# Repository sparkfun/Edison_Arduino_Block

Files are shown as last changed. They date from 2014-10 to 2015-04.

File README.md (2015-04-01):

SparkFun Edison Arduino Block
=============================

SparkFun Edison Arduino Block

[*SparkFun Edison Arduino Block(DEV-13036)*](https://www.sparkfun.com/products/13036)

Piggyback an Arduino onto your Edison with the Edison Arduino Pro board. This board features the same ATmega328P you'll find on Arduino Uno's, Pro's, and Pro Mini's. The 8-bit microcontroller workhorse is connected to the Edison via a selectable UART, so your Edison can interact with the Arduino over a serial interface.

The GPIO pins of the Arduino are all broken out to the familiar Pro Mini form factor. You can jump wires off of them to control LEDs, motors, or sensors. Or connect it straight up to a Pro Mini shield.

Repository Contents
-------------------
* **/Firmware** - Example Arduino sketch
* **/Hardware** - All Eagle design files (.brd, .sch)
* **/Production** - Test bed files and production panel files

License Information
--------------------
The hardware is released under [Creative Commons ShareAlike 4.0 International](https://creativecommons.org/licenses/by-sa/4.0/).
The code is beerware; if you see me (or any other SparkFun employee) at the local, and you've found our code helpful, please buy us a round!

Distributed as-is; no warranty is given.

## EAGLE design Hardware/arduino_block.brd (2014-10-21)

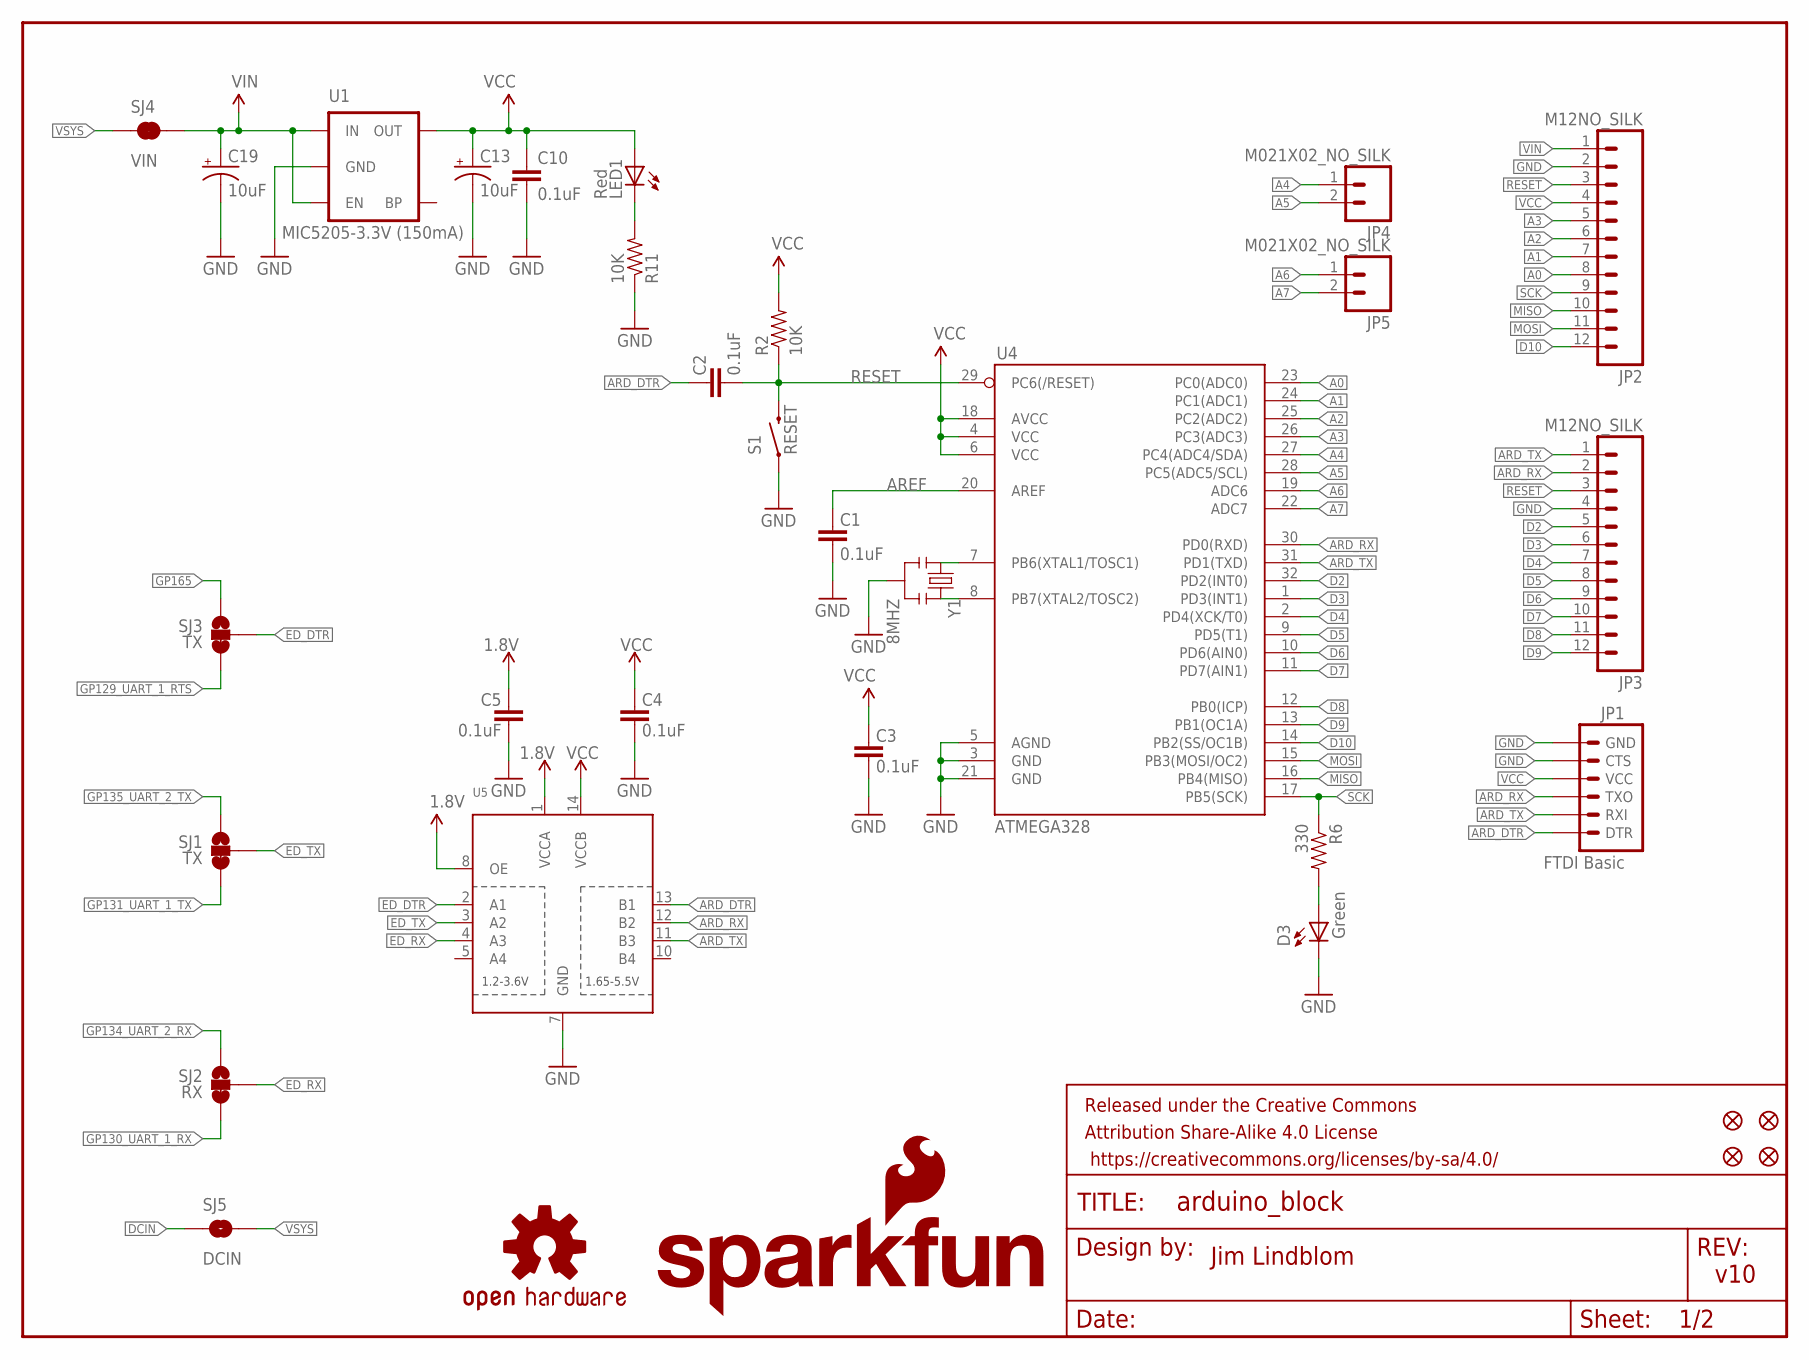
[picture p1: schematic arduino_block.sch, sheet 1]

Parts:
C1, C2, C3, C4, C5, C10: 0.1uF; 0603-CAP
C13, C19: 10uF; EIA3216
D3: Green; 0603-LED-ALT1
FID1, FID2, FID3, FID4: FIDUCIAL1X2; FIDUCIAL-1X2
FRAME1: FRAME-LETTER; CREATIVE_COMMONS
JP1: FTDI Basic; 1X06
JP2, JP3: M12NO_SILK; 1X12_NO_SILK
JP4, JP5: M021X02_NO_SILK; 1X02_NO_SILK
LED1: Red; 0603-LED-ALT1
LOGO1: OSHW-LOGOS; OSHW-LOGO-S
LOGO4: SFE_LOGO_NAME_FLAME.1_INCH; SFE_LOGO_NAME_FLAME_.1
R2, R11: 10K; 0603-RES
R6: 330; 0603-RES
S1: RESET; TACTILE_SWITCH-SMD-RIGHT-ANGLE
SJ1, SJ3: TX; PAD-JUMPER-3-2OF3_NC_BY_TRACE_YES_SILK_FULL_BOX
SJ2: RX; PAD-JUMPER-3-2OF3_NC_BY_TRACE_YES_SILK_FULL_BOX
SJ4: VIN; PAD-JUMPER-2-NC_BY_TRACE_YES_SILK
SJ5: DCIN; PAD-JUMPER-2-NO_YES_SILK
U1: MIC5205-3.3V (150mA); SOT23-5
U4: ATMEGA328; TQFP32-08
U5: TXB0104PWRSOIC14; SO14
Y1: 8MHZ; RESONATOR-SMD

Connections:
1.8V: C5.2, U5.1 (VCCA), U5.8 (OE); also elsewhere on the board
A0: JP2.8, U4.23 (PC0(ADC0))
A1: JP2.7, U4.24 (PC1(ADC1))
A2: JP2.6, U4.25 (PC2(ADC2))
A3: JP2.5, U4.26 (PC3(ADC3))
A4: JP4.1, U4.27 (PC4(ADC4/SDA))
A5: JP4.2, U4.28 (PC5(ADC5/SCL))
A6: JP5.1, U4.19 (ADC6)
A7: JP5.2, U4.22 (ADC7)
ARD_DTR: C2.2, JP1.1 (DTR), U5.13 (B1)
ARD_RX: JP1.3 (TXO), JP3.2, U4.30 (PD0(RXD)), U5.12 (B2)
ARD_TX: JP1.2 (RXI), JP3.1, U4.31 (PD1(TXD)), U5.11 (B3)
AREF: C1.2, U4.20 (AREF)
D2: JP3.5, U4.32 (PD2(INT0))
D3: JP3.6, U4.1 (PD3(INT1))
D4: JP3.7, U4.2 (PD4(XCK/T0))
D5: JP3.8, U4.9 (PD5(T1))
D6: JP3.9, U4.10 (PD6(AIN0))
D7: JP3.10, U4.11 (PD7(AIN1))
D8: JP3.11, U4.12 (PB0(ICP))
D9: JP3.12, U4.13 (PB1(OC1A))
D10: JP2.12, U4.14 (PB2(SS/OC1B))
DCIN: SJ5.1; also elsewhere on the board
ED_DTR: SJ3.2, U5.2 (A1)
ED_RX: SJ2.2, U5.4 (A3)
ED_TX: SJ1.2, U5.3 (A2)
GND: C1.1, C3.1, C4.1, C5.1, C10.2, C13.C (-), C19.C (-), D3.C, JP1.5 (CTS), JP1.6 (GND), JP2.2, JP3.4, R11.1, S1.1, U1.2 (GND), U4.3 (GND), U4.5 (AGND), U4.21 (GND), U5.7 (GND), Y1.2; also elsewhere on the board
GP129_UART_1_RTS: SJ3.3; also elsewhere on the board
GP130_UART_1_RX: SJ2.3; also elsewhere on the board
GP131_UART_1_TX: SJ1.3; also elsewhere on the board
GP134_UART_2_RX: SJ2.1; also elsewhere on the board
GP135_UART_2_TX: SJ1.1; also elsewhere on the board
GP165: SJ3.1; also elsewhere on the board
MISO: JP2.10, U4.16 (PB4(MISO))
MOSI: JP2.11, U4.15 (PB3(MOSI/OC2))
unnamed: U4.8 (PB7(XTAL2/TOSC2)), Y1.3
unnamed: U4.7 (PB6(XTAL1/TOSC1)), Y1.1
unnamed: LED1.C, R11.2
unnamed: D3.A, R6.2
RESET: C2.1, JP2.3, JP3.3, R2.1, S1.2, U4.29 (PC6(/RESET))
SCK: JP2.9, R6.1, U4.17 (PB5(SCK))
VCC: C3.2, C4.2, C10.1, C13.A (+), JP1.4 (VCC), JP2.4, LED1.A, R2.2, U1.5 (OUT), U4.4 (VCC), U4.6 (VCC), U4.18 (AVCC), U5.14 (VCCB)
VIN: C19.A (+), JP2.1, SJ4.2, U1.1 (IN), U1.3 (EN)
VSYS: SJ4.1, SJ5.2; also elsewhere on the board

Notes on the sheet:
v10
Jim Lindblom

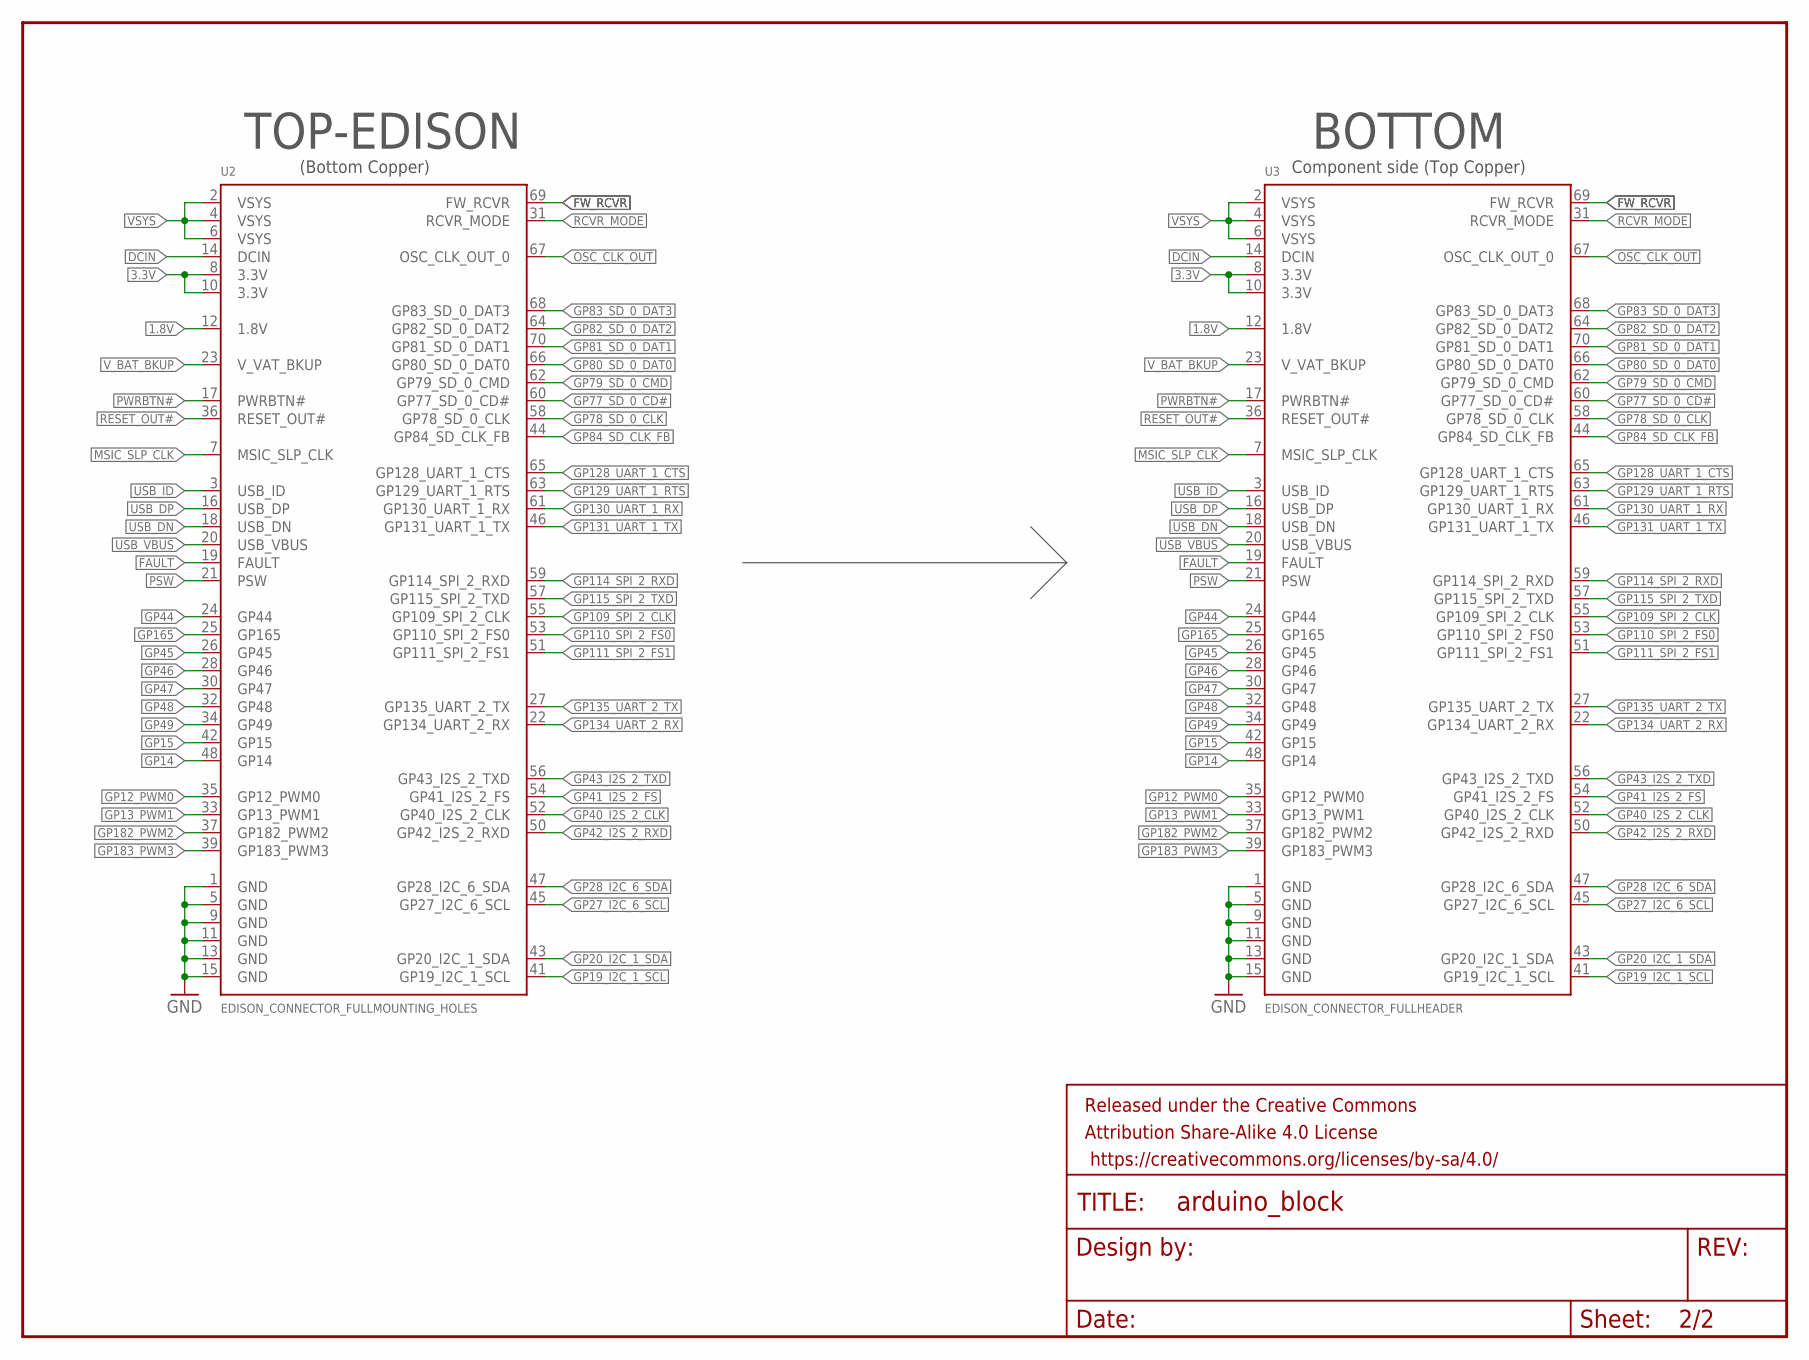
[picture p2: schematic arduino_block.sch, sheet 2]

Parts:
FRAME2: FRAME-LETTER; CREATIVE_COMMONS
U2: EDISON_CONNECTOR_FULLMOUNTING_HOLES; EDISON_DAUGHTER
U3: EDISON_CONNECTOR_FULLHEADER; DF40C-70DP-0.4(51)

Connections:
1.8V: U2.12 (1.8V), U3.12 (1.8V); also elsewhere on the board
3.3V: U2.8 (3.3V), U2.10 (3.3V), U3.8 (3.3V), U3.10 (3.3V)
DCIN: U2.14 (DCIN), U3.14 (DCIN); also elsewhere on the board
FAULT: U2.19 (FAULT), U3.19 (FAULT)
FW_RCVR: U2.69 (FW_RCVR), U3.69 (FW_RCVR)
GND: U2.1 (GND), U2.5 (GND), U2.9 (GND), U2.11 (GND), U2.13 (GND), U2.15 (GND), U3.1 (GND), U3.5 (GND), U3.9 (GND), U3.11 (GND), U3.13 (GND), U3.15 (GND); also elsewhere on the board
GP12_PWM0: U2.35 (GP12_PWM0), U3.35 (GP12_PWM0)
GP13_PWM1: U2.33 (GP13_PWM1), U3.33 (GP13_PWM1)
GP14: U2.48 (GP14), U3.48 (GP14)
GP15: U2.42 (GP15), U3.42 (GP15)
GP19_I2C_1_SCL: U2.41 (GP19_I2C_1_SCL), U3.41 (GP19_I2C_1_SCL)
GP20_I2C_1_SDA: U2.43 (GP20_I2C_1_SDA), U3.43 (GP20_I2C_1_SDA)
GP27_I2C_6_SCL: U2.45 (GP27_I2C_6_SCL), U3.45 (GP27_I2C_6_SCL)
GP28_I2C_6_SDA: U2.47 (GP28_I2C_6_SDA), U3.47 (GP28_I2C_6_SDA)
GP40_I2S_2_CLK: U2.52 (GP40_I2S_2_CLK), U3.52 (GP40_I2S_2_CLK)
GP41_I2S_2_FS: U2.54 (GP41_I2S_2_FS), U3.54 (GP41_I2S_2_FS)
GP42_I2S_2_RXD: U2.50 (GP42_I2S_2_RXD), U3.50 (GP42_I2S_2_RXD)
GP43_I2S_2_TXD: U2.56 (GP43_I2S_2_TXD), U3.56 (GP43_I2S_2_TXD)
GP44: U2.24 (GP44), U3.24 (GP44)
GP45: U2.26 (GP45), U3.26 (GP45)
GP46: U2.28 (GP46), U3.28 (GP46)
GP47: U2.30 (GP47), U3.30 (GP47)
GP48: U2.32 (GP48), U3.32 (GP48)
GP49: U2.34 (GP49), U3.34 (GP49)
GP77_SD_0_CD#: U2.60 (GP77_SD_0_CD#), U3.60 (GP77_SD_0_CD#)
GP78_SD_0_CLK: U2.58 (GP78_SD_0_CLK), U3.58 (GP78_SD_0_CLK)
GP79_SD_0_CMD: U2.62 (GP79_SD_0_CMD), U3.62 (GP79_SD_0_CMD)
GP80_SD_0_DAT0: U2.66 (GP80_SD_0_DAT0), U3.66 (GP80_SD_0_DAT0)
GP81_SD_0_DAT1: U2.70 (GP81_SD_0_DAT1), U3.70 (GP81_SD_0_DAT1)
GP82_SD_0_DAT2: U2.64 (GP82_SD_0_DAT2), U3.64 (GP82_SD_0_DAT2)
GP83_SD_0_DAT3: U2.68 (GP83_SD_0_DAT3), U3.68 (GP83_SD_0_DAT3)
GP84_SD_CLK_FB: U2.44 (GP84_SD_CLK_FB), U3.44 (GP84_SD_CLK_FB)
GP109_SPI_2_CLK: U2.55 (GP109_SPI_2_CLK), U3.55 (GP109_SPI_2_CLK)
GP110_SPI_2_FS0: U2.53 (GP110_SPI_2_FS0), U3.53 (GP110_SPI_2_FS0)
GP111_SPI_2_FS1: U2.51 (GP111_SPI_2_FS1), U3.51 (GP111_SPI_2_FS1)
GP114_SPI_2_RXD: U2.59 (GP114_SPI_2_RXD), U3.59 (GP114_SPI_2_RXD)
GP115_SPI_2_TXD: U2.57 (GP115_SPI_2_TXD), U3.57 (GP115_SPI_2_TXD)
GP128_UART_1_CTS: U2.65 (GP128_UART_1_CTS), U3.65 (GP128_UART_1_CTS)
GP129_UART_1_RTS: U2.63 (GP129_UART_1_RTS), U3.63 (GP129_UART_1_RTS); also elsewhere on the board
GP130_UART_1_RX: U2.61 (GP130_UART_1_RX), U3.61 (GP130_UART_1_RX); also elsewhere on the board
GP131_UART_1_TX: U2.46 (GP131_UART_1_TX), U3.46 (GP131_UART_1_TX); also elsewhere on the board
GP134_UART_2_RX: U2.22 (GP134_UART_2_RX), U3.22 (GP134_UART_2_RX); also elsewhere on the board
GP135_UART_2_TX: U2.27 (GP135_UART_2_TX), U3.27 (GP135_UART_2_TX); also elsewhere on the board
GP165: U2.25 (GP165), U3.25 (GP165); also elsewhere on the board
GP182_PWM2: U2.37 (GP182_PWM2), U3.37 (GP182_PWM2)
GP183_PWM3: U2.39 (GP183_PWM3), U3.39 (GP183_PWM3)
MSIC_SLP_CLK: U2.7 (MSIC_SLP_CLK), U3.7 (MSIC_SLP_CLK)
OSC_CLK_OUT: U2.67 (OSC_CLK_OUT_0), U3.67 (OSC_CLK_OUT_0)
PSW: U2.21 (PSW), U3.21 (PSW)
PWRBTN#: U2.17 (PWRBTN#), U3.17 (PWRBTN#)
RCVR_MODE: U2.31 (RCVR_MODE), U3.31 (RCVR_MODE)
RESET_OUT#: U2.36 (RESET_OUT#), U3.36 (RESET_OUT#)
USB_DN: U2.18 (USB_DN), U3.18 (USB_DN)
USB_DP: U2.16 (USB_DP), U3.16 (USB_DP)
USB_ID: U2.3 (USB_ID), U3.3 (USB_ID)
USB_VBUS: U2.20 (USB_VBUS), U3.20 (USB_VBUS)
VSYS: U2.2 (VSYS), U2.4 (VSYS), U2.6 (VSYS), U3.2 (VSYS), U3.4 (VSYS), U3.6 (VSYS); also elsewhere on the board
V_BAT_BKUP: U2.23 (V_VAT_BKUP), U3.23 (V_VAT_BKUP)

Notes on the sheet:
TOP-EDISON
BOTTOM
Component side (Top Copper)
(Bottom Copper)

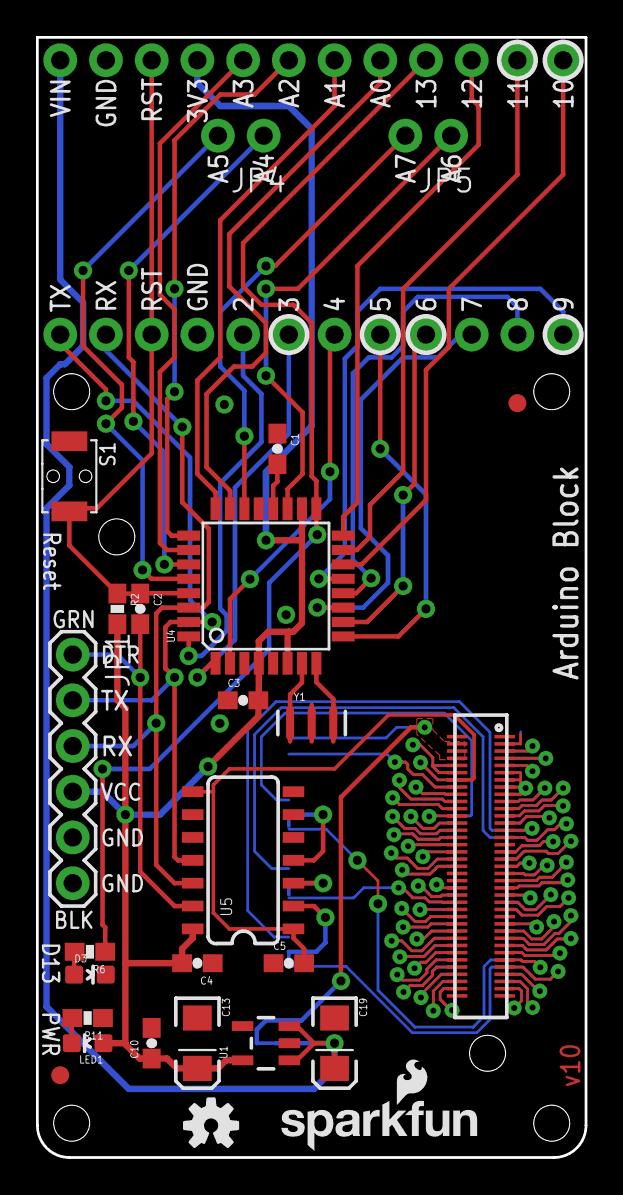
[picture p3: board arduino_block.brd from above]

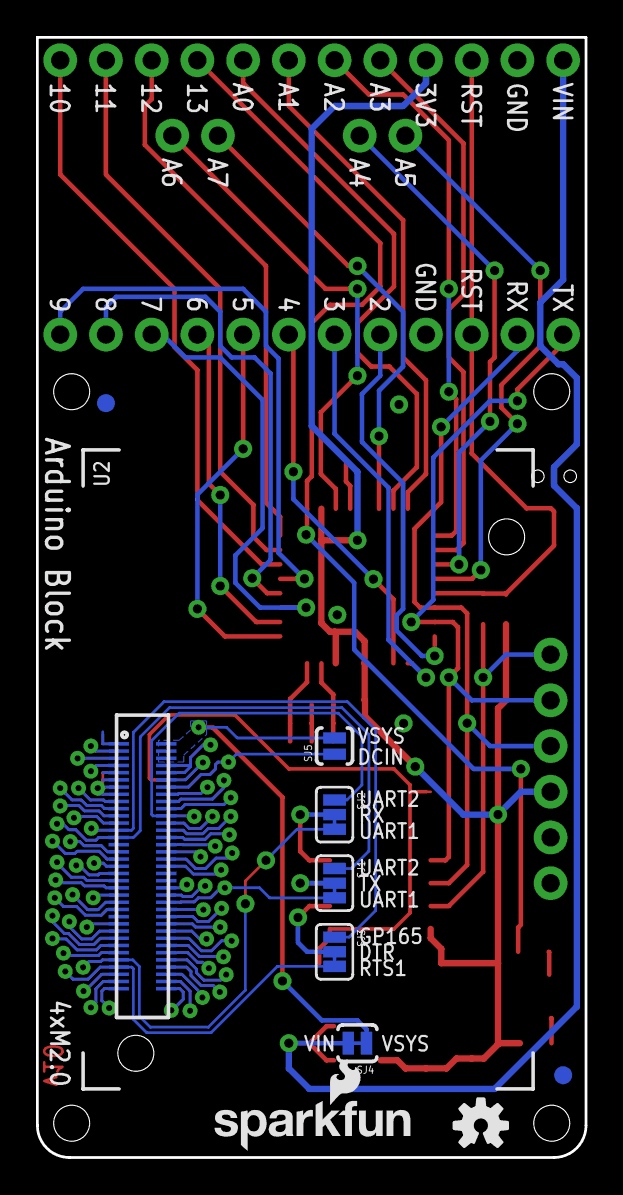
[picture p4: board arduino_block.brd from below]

Board: 2 copper layers, 30.5 x 62.2 mm, 40 parts (11 on the bottom side), 92 nets.

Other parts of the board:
LOGO2: OSHW-LOGOS; OSHW-LOGO-S
LOGO3: SFE_LOGO_NAME_FLAME.1_INCH; SFE_LOGO_NAME_FLAME_.1

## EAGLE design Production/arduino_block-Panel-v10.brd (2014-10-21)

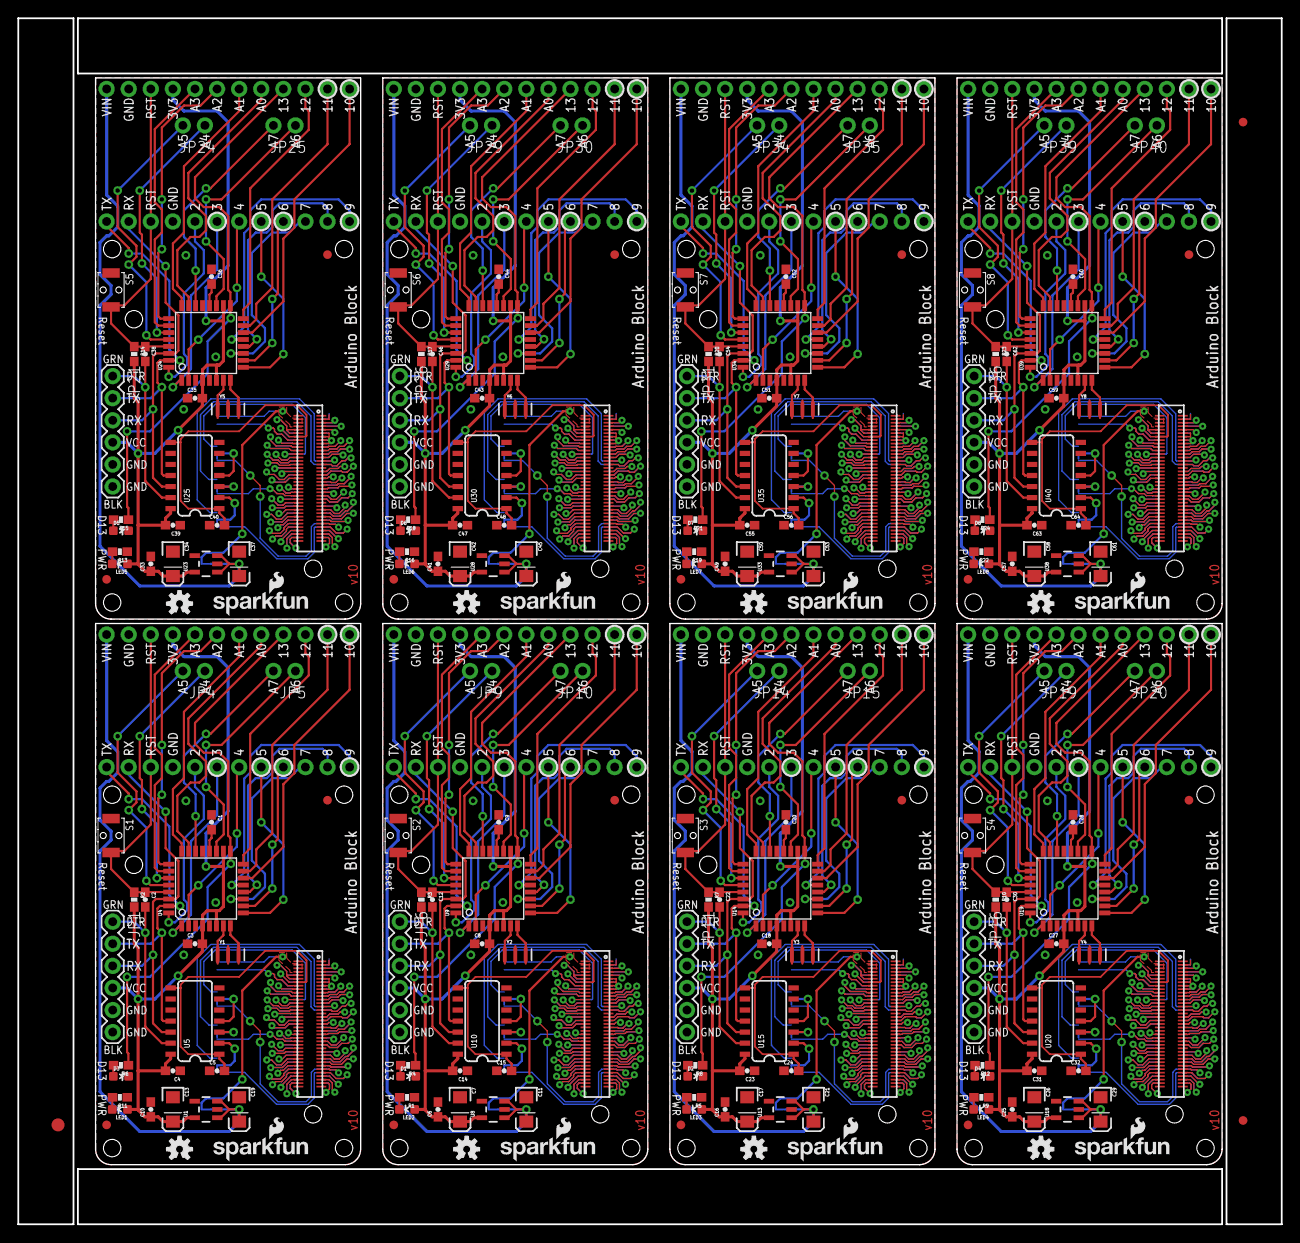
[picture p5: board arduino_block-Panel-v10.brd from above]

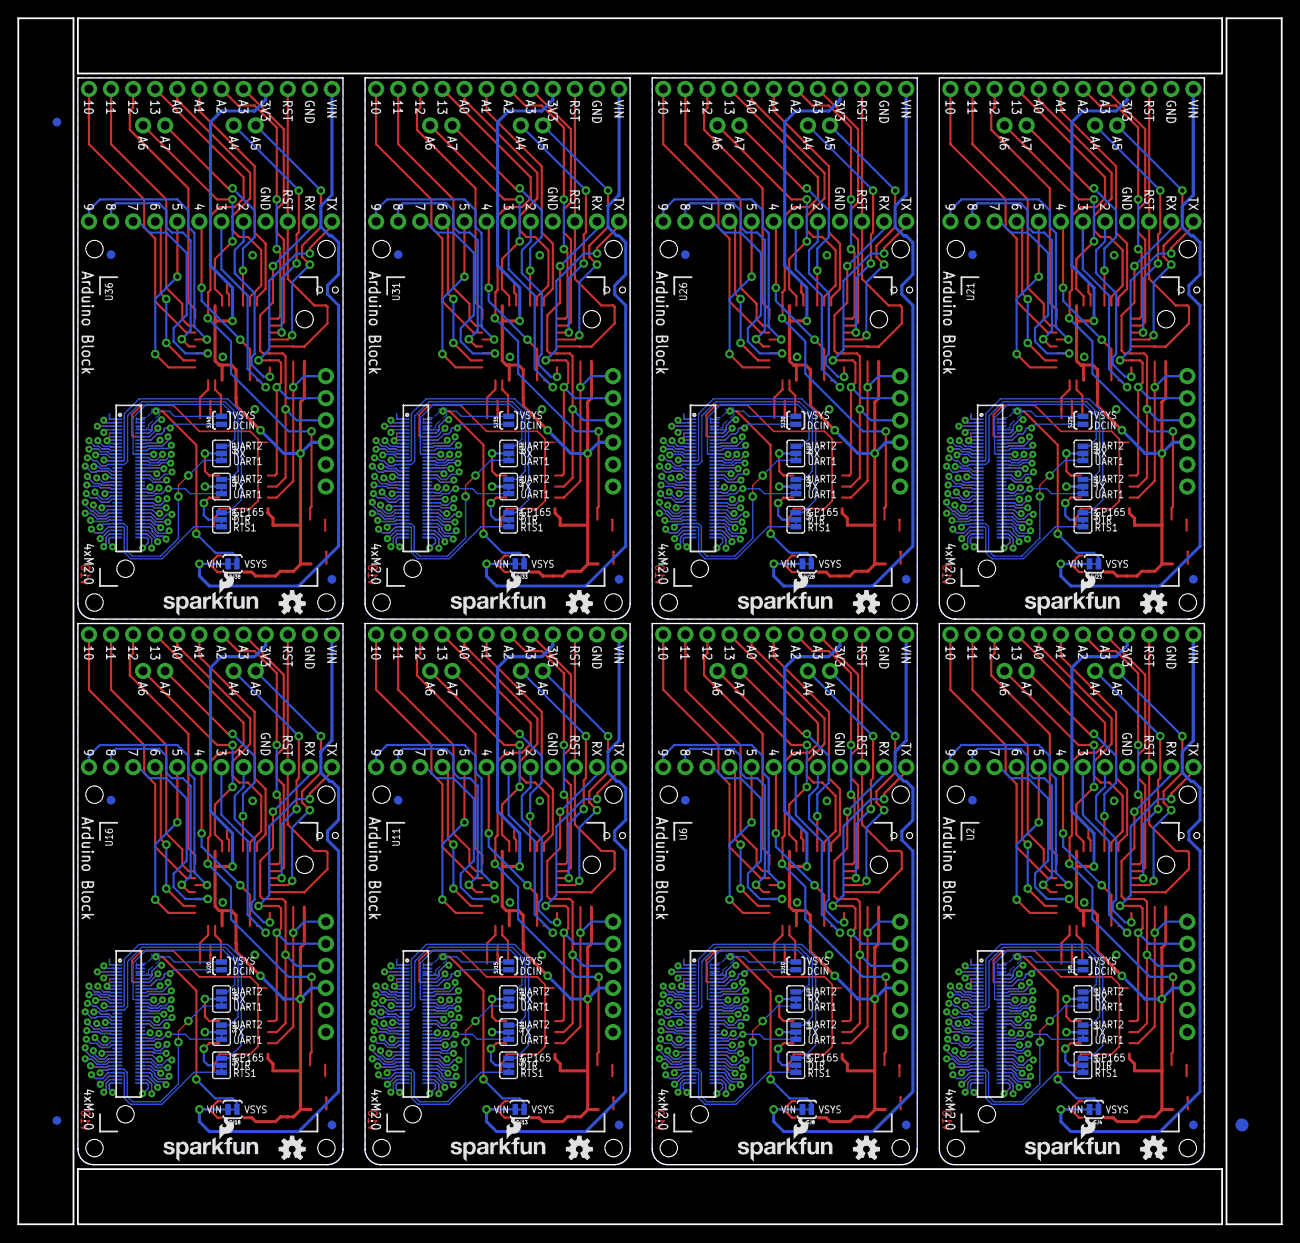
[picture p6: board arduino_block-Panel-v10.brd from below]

Board: 2 copper layers, 145.3 x 138.7 mm, 310 parts (91 on the bottom side), 736 nets.

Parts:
C1, C2, C3, C4, C5, C6, C8, C9, C10, C12, C14, C15, C16, C18, C20, C22, C23, C24, C25, C27, C28, C30, C31, C32, C33, C35, C36, C38, C39, C40, C41, C43, C44, C46, C47, C48, C49, C51, C52, C54, C55, C56, C57, C59, C60, C62, C63, C64: 0.1uF; 0603-CAP
C7, C11, C13, C17, C19, C21, C26, C29, C34, C37, C42, C45, C50, C53, C58, C61: 10uF; EIA3216
D1, D2, D3, D4, D5, D6, D7, D8: Green; 0603-LED-ALT1
E$1, E$2: FIDUCIAL-1.5X3
E$3, E$4, E$5, E$6: FIDUCIAL-1X2
FID1, FID2, FID3, FID4, FID5, FID6, FID7, FID8, FID9, FID10, FID11, FID12, FID13, FID14, FID15, FID16, FID17, FID18, FID19, FID20, FID21, FID22, FID23, FID24, FID25, FID26, FID27, FID28, FID29, FID30, FID31, FID32: FIDUCIAL1X2; FIDUCIAL-1X2
JP1, JP6, JP11, JP16, JP21, JP26, JP31, JP36: FTDI Basic; 1X06
JP2, JP3, JP7, JP8, JP12, JP13, JP17, JP18, JP22, JP23, JP27, JP28, JP32, JP33, JP37, JP38: M12NO_SILK; 1X12_NO_SILK
JP4, JP5, JP9, JP10, JP14, JP15, JP19, JP20, JP24, JP25, JP29, JP30, JP34, JP35, JP39, JP40: M021X02_NO_SILK; 1X02_NO_SILK
LED1, LED2, LED3, LED4, LED5, LED6, LED7, LED8: Red; 0603-LED-ALT1
LOGO1, LOGO2, LOGO5, LOGO7, LOGO9, LOGO11, LOGO13, LOGO15, LOGO17, LOGO19, LOGO21, LOGO23, LOGO25, LOGO27, LOGO29, LOGO31: OSHW-LOGOS; OSHW-LOGO-S
LOGO3, LOGO4, LOGO6, LOGO8, LOGO10, LOGO12, LOGO14, LOGO16, LOGO18, LOGO20, LOGO22, LOGO24, LOGO26, LOGO28, LOGO30, LOGO32: SFE_LOGO_NAME_FLAME.1_INCH; SFE_LOGO_NAME_FLAME_.1
R1, R2, R3, R5, R7, R9, R10, R11, R13, R14, R16, R17, R19, R20, R22, R23: 10K; 0603-RES
R4, R6, R8, R12, R15, R18, R21, R24: 330; 0603-RES
S1, S2, S3, S4, S5, S6, S7, S8: RESET; TACTILE_SWITCH-SMD-RIGHT-ANGLE
SJ1, SJ3, SJ6, SJ9, SJ11, SJ14, SJ16, SJ19, SJ21, SJ24, SJ26, SJ29, SJ31, SJ34, SJ36, SJ39: TX; PAD-JUMPER-3-2OF3_NC_BY_TRACE_YES_SILK_FULL_BOX
SJ2, SJ7, SJ12, SJ17, SJ22, SJ27, SJ32, SJ37: RX; PAD-JUMPER-3-2OF3_NC_BY_TRACE_YES_SILK_FULL_BOX
SJ4, SJ8, SJ13, SJ18, SJ23, SJ28, SJ33, SJ38: VIN; PAD-JUMPER-2-NC_BY_TRACE_YES_SILK
SJ5, SJ10, SJ15, SJ20, SJ25, SJ30, SJ35, SJ40: DCIN; PAD-JUMPER-2-NO_YES_SILK
U1, U8, U13, U18, U23, U28, U33, U38: MIC5205-3.3V (150mA); SOT23-5
U2, U6, U11, U16, U21, U26, U31, U36: EDISON_CONNECTOR_FULLMOUNTING_HOLES; EDISON_DAUGHTER
U3, U7, U12, U17, U22, U27, U32, U37: EDISON_CONNECTOR_FULLHEADER; DF40C-70DP-0.4(51)
U4, U9, U14, U19, U24, U29, U34, U39: ATMEGA328; TQFP32-08
U5, U10, U15, U20, U25, U30, U35, U40: SO14
Y1, Y2, Y3, Y4, Y5, Y6, Y7, Y8: 8MHZ; RESONATOR-SMD

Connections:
1.8V: C5.2, U2.12, U3.12, U5.1, U5.8
1.8V1: C15.2, U6.12, U7.12, U10.1, U10.8
1.8V2: C24.2, U11.12, U12.12, U15.1, U15.8
1.8V3: C32.2, U16.12, U17.12, U20.1, U20.8
1.8V4: C40.2, U21.12, U22.12, U25.1, U25.8
1.8V5: C48.2, U26.12, U27.12, U30.1, U30.8
1.8V6: C56.2, U31.12, U32.12, U35.1, U35.8
1.8V7: C64.2, U36.12, U37.12, U40.1, U40.8
3.3V: U2.8, U2.10, U3.8, U3.10
3.3V1: U6.8, U6.10, U7.8, U7.10
3.3V2: U11.8, U11.10, U12.8, U12.10
3.3V3: U16.8, U16.10, U17.8, U17.10
3.3V4: U21.8, U21.10, U22.8, U22.10
3.3V5: U26.8, U26.10, U27.8, U27.10
3.3V6: U31.8, U31.10, U32.8, U32.10
3.3V7: U36.8, U36.10, U37.8, U37.10
A0: JP2.8, U4.23
A1: JP2.7, U4.24
A2: JP2.6, U4.25
A3: JP2.5, U4.26
A4: JP4.1, U4.27
A5: JP4.2, U4.28
A6: JP5.1, U4.19
A7: JP5.2, U4.22
A8: JP9.2, U9.28
A9: JP9.1, U9.27
A10: JP7.5, U9.26
A11: JP7.6, U9.25
A12: JP7.7, U9.24
A13: JP7.8, U9.23
A14: JP10.1, U9.19
A15: JP10.2, U9.22
A16: JP14.2, U14.28
A17: JP14.1, U14.27
A18: JP12.5, U14.26
A19: JP12.6, U14.25
A20: JP12.7, U14.24
A21: JP12.8, U14.23
A22: JP15.1, U14.19
A23: JP15.2, U14.22
A24: JP19.2, U19.28
A25: JP19.1, U19.27
A26: JP17.5, U19.26
A27: JP17.6, U19.25
A28: JP17.7, U19.24
A29: JP17.8, U19.23
A30: JP20.1, U19.19
A31: JP20.2, U19.22
A32: JP24.2, U24.28
A33: JP24.1, U24.27
A34: JP22.5, U24.26
A35: JP22.6, U24.25
A36: JP22.7, U24.24
A37: JP22.8, U24.23
A38: JP25.1, U24.19
A39: JP25.2, U24.22
A40: JP29.2, U29.28
A41: JP29.1, U29.27
A42: JP27.5, U29.26
A43: JP27.6, U29.25
A44: JP27.7, U29.24
A45: JP27.8, U29.23
A46: JP30.1, U29.19
A47: JP30.2, U29.22
A48: JP34.2, U34.28
A49: JP34.1, U34.27
A50: JP32.5, U34.26
A51: JP32.6, U34.25
A52: JP32.7, U34.24
A53: JP32.8, U34.23
A54: JP35.1, U34.19
A55: JP35.2, U34.22
A56: JP39.2, U39.28
A57: JP39.1, U39.27
A58: JP37.5, U39.26
A59: JP37.6, U39.25
A60: JP37.7, U39.24
A61: JP37.8, U39.23
A62: JP40.1, U39.19
A63: JP40.2, U39.22
ARD_DTR: C2.2, JP1.1, U5.13
ARD_DTR1: C12.2, JP6.1, U10.13
ARD_DTR2: C22.2, JP11.1, U15.13
ARD_DTR3: C30.2, JP16.1, U20.13
ARD_DTR4: C38.2, JP21.1, U25.13
ARD_DTR5: C46.2, JP26.1, U30.13
ARD_DTR6: C54.2, JP31.1, U35.13
ARD_DTR7: C62.2, JP36.1, U40.13
ARD_RX: JP1.3, JP3.2, U4.30, U5.12
ARD_RX1: JP6.3, JP8.2, U9.30, U10.12
ARD_RX2: JP11.3, JP13.2, U14.30, U15.12
ARD_RX3: JP16.3, JP18.2, U19.30, U20.12
ARD_RX4: JP21.3, JP23.2, U24.30, U25.12
ARD_RX5: JP26.3, JP28.2, U29.30, U30.12
ARD_RX6: JP31.3, JP33.2, U34.30, U35.12
ARD_RX7: JP36.3, JP38.2, U39.30, U40.12
ARD_TX: JP1.2, JP3.1, U4.31, U5.11
ARD_TX1: JP6.2, JP8.1, U9.31, U10.11
ARD_TX2: JP11.2, JP13.1, U14.31, U15.11
ARD_TX3: JP16.2, JP18.1, U19.31, U20.11
ARD_TX4: JP21.2, JP23.1, U24.31, U25.11
ARD_TX5: JP26.2, JP28.1, U29.31, U30.11
ARD_TX6: JP31.2, JP33.1, U34.31, U35.11
ARD_TX7: JP36.2, JP38.1, U39.31, U40.11
AREF: C1.2, U4.20
AREF1: C9.2, U9.20
AREF2: C20.2, U14.20
AREF3: C28.2, U19.20
AREF4: C36.2, U24.20
AREF5: C44.2, U29.20
AREF6: C52.2, U34.20
AREF7: C60.2, U39.20
D1: JP8.12, U9.13
D2: JP3.5, U4.32
D3: JP3.6, U4.1
D4: JP3.7, U4.2
D5: JP3.8, U4.9
D6: JP3.9, U4.10
D7: JP3.10, U4.11
D8: JP3.11, U4.12
D9: JP3.12, U4.13
D10: JP2.12, U4.14
D11: JP8.11, U9.12
D12: JP8.5, U9.32
D13: JP8.6, U9.1
D14: JP8.7, U9.2
D15: JP8.8, U9.9
D16: JP8.9, U9.10
D17: JP8.10, U9.11
D18: JP7.12, U9.14
D19: JP13.12, U14.13
D20: JP13.11, U14.12
D21: JP13.5, U14.32
D22: JP13.6, U14.1
D23: JP13.7, U14.2
D24: JP13.8, U14.9
D25: JP13.9, U14.10
D26: JP13.10, U14.11
D27: JP12.12, U14.14
D28: JP18.12, U19.13
D29: JP18.11, U19.12
D30: JP18.5, U19.32
D31: JP18.6, U19.1
D32: JP18.7, U19.2
D33: JP18.8, U19.9
D34: JP18.9, U19.10
D35: JP18.10, U19.11
D36: JP17.12, U19.14
D37: JP23.12, U24.13
D38: JP23.11, U24.12
D39: JP23.5, U24.32
D40: JP23.6, U24.1
D41: JP23.7, U24.2
D42: JP23.8, U24.9
D43: JP23.9, U24.10
D44: JP23.10, U24.11
D45: JP22.12, U24.14
D46: JP28.12, U29.13
D47: JP28.11, U29.12
D48: JP28.5, U29.32
D49: JP28.6, U29.1
D50: JP28.7, U29.2
D51: JP28.8, U29.9
D52: JP28.9, U29.10
D53: JP28.10, U29.11
D54: JP27.12, U29.14
D55: JP33.12, U34.13
D56: JP33.11, U34.12
D57: JP33.5, U34.32
D58: JP33.6, U34.1
D59: JP33.7, U34.2
D60: JP33.8, U34.9
D61: JP33.9, U34.10
D62: JP33.10, U34.11
D63: JP32.12, U34.14
D64: JP38.12, U39.13
D65: JP38.11, U39.12
D66: JP38.5, U39.32
D67: JP38.6, U39.1
D68: JP38.7, U39.2
D69: JP38.8, U39.9
D70: JP38.9, U39.10
D71: JP38.10, U39.11
D72: JP37.12, U39.14
DCIN: SJ5.1, U2.14, U3.14
DCIN1: SJ10.1, U6.14, U7.14
DCIN2: SJ15.1, U11.14, U12.14
DCIN3: SJ20.1, U16.14, U17.14
DCIN4: SJ25.1, U21.14, U22.14
DCIN5: SJ30.1, U26.14, U27.14
DCIN6: SJ35.1, U31.14, U32.14
DCIN7: SJ40.1, U36.14, U37.14
ED_DTR: SJ3.2, U5.2
ED_DTR1: SJ9.2, U10.2
ED_DTR2: SJ14.2, U15.2
ED_DTR3: SJ19.2, U20.2
ED_DTR4: SJ24.2, U25.2
ED_DTR5: SJ29.2, U30.2
ED_DTR6: SJ34.2, U35.2
ED_DTR7: SJ39.2, U40.2
ED_RX: SJ2.2, U5.4
ED_RX1: SJ7.2, U10.4
ED_RX2: SJ12.2, U15.4
ED_RX3: SJ17.2, U20.4
ED_RX4: SJ22.2, U25.4
ED_RX5: SJ27.2, U30.4
ED_RX6: SJ32.2, U35.4
ED_RX7: SJ37.2, U40.4
ED_TX: SJ1.2, U5.3
ED_TX1: SJ6.2, U10.3
ED_TX2: SJ11.2, U15.3
ED_TX3: SJ16.2, U20.3
ED_TX4: SJ21.2, U25.3
ED_TX5: SJ26.2, U30.3
ED_TX6: SJ31.2, U35.3
ED_TX7: SJ36.2, U40.3
FAULT: U2.19, U3.19
FAULT1: U6.19, U7.19
FAULT2: U11.19, U12.19
FAULT3: U16.19, U17.19
FAULT4: U21.19, U22.19
FAULT5: U26.19, U27.19
FAULT6: U31.19, U32.19
FAULT7: U36.19, U37.19
FW_RCVR: U2.69, U3.69
FW_RCVR1: U6.69, U7.69
FW_RCVR2: U11.69, U12.69
FW_RCVR3: U16.69, U17.69
FW_RCVR4: U21.69, U22.69
FW_RCVR5: U26.69, U27.69
FW_RCVR6: U31.69, U32.69
FW_RCVR7: U36.69, U37.69
GND: C1.1, C3.1, C4.1, C5.1, C10.2, C13.C, C19.C, D3.C, JP1.5, JP1.6, JP2.2, JP3.4, R11.1, S1.1, U1.2, U2.1, U2.5, U2.9, U2.11, U2.13, U2.15, U3.1, U3.5, U3.9, U3.11, U3.13, U3.15, U4.3, U4.5, U4.21, U5.7, Y1.2
GND1: C6.2, C7.C, C8.1, C9.1, C11.C, C14.1, C15.1, D1.C, JP6.5, JP6.6, JP7.2, JP8.4, R1.1, S2.1, U6.1, U6.5, U6.9, U6.11, U6.13, U6.15, U7.1, U7.5, U7.9, U7.11, U7.13, U7.15, U8.2, U9.3, U9.5, U9.21, U10.7, Y2.2
GND2: C16.2, C17.C, C18.1, C20.1, C21.C, C23.1, C24.1, D2.C, JP11.5, JP11.6, JP12.2, JP13.4, R5.1, S3.1, U11.1, U11.5, U11.9, U11.11, U11.13, U11.15, U12.1, U12.5, U12.9, U12.11, U12.13, U12.15, U13.2, U14.3, U14.5, U14.21, U15.7, Y3.2
GND3: C25.2, C26.C, C27.1, C28.1, C29.C, C31.1, C32.1, D4.C, JP16.5, JP16.6, JP17.2, JP18.4, R9.1, S4.1, U16.1, U16.5, U16.9, U16.11, U16.13, U16.15, U17.1, U17.5, U17.9, U17.11, U17.13, U17.15, U18.2, U19.3, U19.5, U19.21, U20.7, Y4.2
GND4: C33.2, C34.C, C35.1, C36.1, C37.C, C39.1, C40.1, D5.C, JP21.5, JP21.6, JP22.2, JP23.4, R13.1, S5.1, U21.1, U21.5, U21.9, U21.11, U21.13, U21.15, U22.1, U22.5, U22.9, U22.11, U22.13, U22.15, U23.2, U24.3, U24.5, U24.21, U25.7, Y5.2
GND5: C41.2, C42.C, C43.1, C44.1, C45.C, C47.1, C48.1, D6.C, JP26.5, JP26.6, JP27.2, JP28.4, R16.1, S6.1, U26.1, U26.5, U26.9, U26.11, U26.13, U26.15, U27.1, U27.5, U27.9, U27.11, U27.13, U27.15, U28.2, U29.3, U29.5, U29.21, U30.7, Y6.2
GND6: C49.2, C50.C, C51.1, C52.1, C53.C, C55.1, C56.1, D7.C, JP31.5, JP31.6, JP32.2, JP33.4, R19.1, S7.1, U31.1, U31.5, U31.9, U31.11, U31.13, U31.15, U32.1, U32.5, U32.9, U32.11, U32.13, U32.15, U33.2, U34.3, U34.5, U34.21, U35.7, Y7.2
GND7: C57.2, C58.C, C59.1, C60.1, C61.C, C63.1, C64.1, D8.C, JP36.5, JP36.6, JP37.2, JP38.4, R22.1, S8.1, U36.1, U36.5, U36.9, U36.11, U36.13, U36.15, U37.1, U37.5, U37.9, U37.11, U37.13, U37.15, U38.2, U39.3, U39.5, U39.21, U40.7, Y8.2
GP1: U6.48, U7.48
GP2: U6.42, U7.42
GP3: U6.34, U7.34
GP4: U6.32, U7.32
GP5: U6.30, U7.30
GP6: U6.28, U7.28
GP7: U6.26, U7.26
GP8: SJ9.1, U6.25, U7.25
GP9: U6.24, U7.24
GP10: U11.48, U12.48
GP11: U11.42, U12.42
GP12: U11.34, U12.34
GP12_PWM0: U2.35, U3.35
GP12_PWM1: U6.35, U7.35
GP12_PWM2: U11.35, U12.35
GP12_PWM3: U16.35, U17.35
GP12_PWM4: U21.35, U22.35
GP12_PWM5: U26.35, U27.35
GP12_PWM6: U31.35, U32.35
GP12_PWM7: U36.35, U37.35
GP13: U11.32, U12.32
GP13_PWM1: U2.33, U3.33
GP13_PWM2: U6.33, U7.33
GP13_PWM3: U11.33, U12.33
GP13_PWM4: U16.33, U17.33
GP13_PWM5: U21.33, U22.33
GP13_PWM6: U26.33, U27.33
GP13_PWM7: U31.33, U32.33
GP13_PWM8: U36.33, U37.33
GP14: U2.48, U3.48
GP15: U2.42, U3.42
GP16: U11.30, U12.30
GP17: U11.28, U12.28
GP18: U11.26, U12.26
GP19: SJ14.1, U11.25, U12.25
GP19_I2C_1_SCL: U2.41, U3.41
GP19_I2C_1_SCL1: U6.41, U7.41
GP19_I2C_1_SCL2: U11.41, U12.41
GP19_I2C_1_SCL3: U16.41, U17.41
GP19_I2C_1_SCL4: U21.41, U22.41
GP19_I2C_1_SCL5: U26.41, U27.41
GP19_I2C_1_SCL6: U31.41, U32.41
GP19_I2C_1_SCL7: U36.41, U37.41
GP20: U11.24, U12.24
GP20_I2C_1_SDA: U2.43, U3.43
GP20_I2C_1_SDA1: U6.43, U7.43
GP20_I2C_1_SDA2: U11.43, U12.43
GP20_I2C_1_SDA3: U16.43, U17.43
GP20_I2C_1_SDA4: U21.43, U22.43
GP20_I2C_1_SDA5: U26.43, U27.43
GP20_I2C_1_SDA6: U31.43, U32.43
GP20_I2C_1_SDA7: U36.43, U37.43
GP21: U16.48, U17.48
GP22: U16.42, U17.42
GP23: U16.34, U17.34
GP24: U16.32, U17.32
GP25: U16.30, U17.30
GP26: U16.28, U17.28
GP27: U16.26, U17.26
GP27_I2C_6_SCL: U2.45, U3.45
GP27_I2C_6_SCL1: U6.45, U7.45
GP27_I2C_6_SCL2: U11.45, U12.45
GP27_I2C_6_SCL3: U16.45, U17.45
GP27_I2C_6_SCL4: U21.45, U22.45
GP27_I2C_6_SCL5: U26.45, U27.45
GP27_I2C_6_SCL6: U31.45, U32.45
GP27_I2C_6_SCL7: U36.45, U37.45
GP28: SJ19.1, U16.25, U17.25
GP28_I2C_6_SDA: U2.47, U3.47
GP28_I2C_6_SDA1: U6.47, U7.47
GP28_I2C_6_SDA2: U11.47, U12.47
GP28_I2C_6_SDA3: U16.47, U17.47
GP28_I2C_6_SDA4: U21.47, U22.47
GP28_I2C_6_SDA5: U26.47, U27.47
GP28_I2C_6_SDA6: U31.47, U32.47
GP28_I2C_6_SDA7: U36.47, U37.47
GP29: U16.24, U17.24
GP30: U21.48, U22.48
GP31: U21.42, U22.42
GP32: U21.34, U22.34
GP33: U21.32, U22.32
GP34: U21.30, U22.30
GP35: U21.28, U22.28
GP36: U21.26, U22.26
GP37: SJ24.1, U21.25, U22.25
GP38: U21.24, U22.24
GP39: U26.48, U27.48
GP40: U26.42, U27.42
GP40_I2S_2_CLK: U2.52, U3.52
GP40_I2S_2_CLK1: U6.52, U7.52
GP40_I2S_2_CLK2: U11.52, U12.52
GP40_I2S_2_CLK3: U16.52, U17.52
GP40_I2S_2_CLK4: U21.52, U22.52
GP40_I2S_2_CLK5: U26.52, U27.52
GP40_I2S_2_CLK6: U31.52, U32.52
GP40_I2S_2_CLK7: U36.52, U37.52
GP41: U26.34, U27.34
GP41_I2S_2_FS: U2.54, U3.54
GP41_I2S_2_FS1: U6.54, U7.54
GP41_I2S_2_FS2: U11.54, U12.54
GP41_I2S_2_FS3: U16.54, U17.54
GP41_I2S_2_FS4: U21.54, U22.54
GP41_I2S_2_FS5: U26.54, U27.54
GP41_I2S_2_FS6: U31.54, U32.54
GP41_I2S_2_FS7: U36.54, U37.54
GP42: U26.32, U27.32
GP42_I2S_2_RXD: U2.50, U3.50
GP42_I2S_2_RXD1: U6.50, U7.50
GP42_I2S_2_RXD2: U11.50, U12.50
GP42_I2S_2_RXD3: U16.50, U17.50
GP42_I2S_2_RXD4: U21.50, U22.50
GP42_I2S_2_RXD5: U26.50, U27.50
GP42_I2S_2_RXD6: U31.50, U32.50
GP42_I2S_2_RXD7: U36.50, U37.50
GP43: U26.30, U27.30
GP43_I2S_2_TXD: U2.56, U3.56
GP43_I2S_2_TXD1: U6.56, U7.56
GP43_I2S_2_TXD2: U11.56, U12.56
GP43_I2S_2_TXD3: U16.56, U17.56
GP43_I2S_2_TXD4: U21.56, U22.56
GP43_I2S_2_TXD5: U26.56, U27.56
GP43_I2S_2_TXD6: U31.56, U32.56
GP43_I2S_2_TXD7: U36.56, U37.56
GP44: U2.24, U3.24
GP45: U2.26, U3.26
GP46: U2.28, U3.28
GP47: U2.30, U3.30
GP48: U2.32, U3.32
GP49: U2.34, U3.34
GP50: U26.28, U27.28
GP51: U26.26, U27.26
GP52: SJ29.1, U26.25, U27.25
GP53: U26.24, U27.24
GP54: U31.48, U32.48
GP55: U31.42, U32.42
GP56: U31.34, U32.34
GP57: U31.32, U32.32
GP58: U31.30, U32.30
GP59: U31.28, U32.28
GP60: U31.26, U32.26
GP61: SJ34.1, U31.25, U32.25
GP62: U31.24, U32.24
GP63: U36.48, U37.48
GP64: U36.42, U37.42
GP65: U36.34, U37.34
GP66: U36.32, U37.32
GP67: U36.30, U37.30
GP68: U36.28, U37.28
GP69: U36.26, U37.26
GP70: SJ39.1, U36.25, U37.25
GP71: U36.24, U37.24
GP77_SD_0_CD#: U2.60, U3.60
GP77_SD_0_CD#1: U6.60, U7.60
GP77_SD_0_CD#2: U11.60, U12.60
GP77_SD_0_CD#3: U16.60, U17.60
GP77_SD_0_CD#4: U21.60, U22.60
GP77_SD_0_CD#5: U26.60, U27.60
GP77_SD_0_CD#6: U31.60, U32.60
GP77_SD_0_CD#7: U36.60, U37.60
GP78_SD_0_CLK: U2.58, U3.58
GP78_SD_0_CLK1: U6.58, U7.58
GP78_SD_0_CLK2: U11.58, U12.58
GP78_SD_0_CLK3: U16.58, U17.58
GP78_SD_0_CLK4: U21.58, U22.58
GP78_SD_0_CLK5: U26.58, U27.58
GP78_SD_0_CLK6: U31.58, U32.58
GP78_SD_0_CLK7: U36.58, U37.58
GP79_SD_0_CMD: U2.62, U3.62
GP79_SD_0_CMD1: U6.62, U7.62
GP79_SD_0_CMD2: U11.62, U12.62
GP79_SD_0_CMD3: U16.62, U17.62
GP79_SD_0_CMD4: U21.62, U22.62
GP79_SD_0_CMD5: U26.62, U27.62
GP79_SD_0_CMD6: U31.62, U32.62
GP79_SD_0_CMD7: U36.62, U37.62
GP80_SD_0_DAT0: U2.66, U3.66
GP80_SD_0_DAT1: U6.66, U7.66
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

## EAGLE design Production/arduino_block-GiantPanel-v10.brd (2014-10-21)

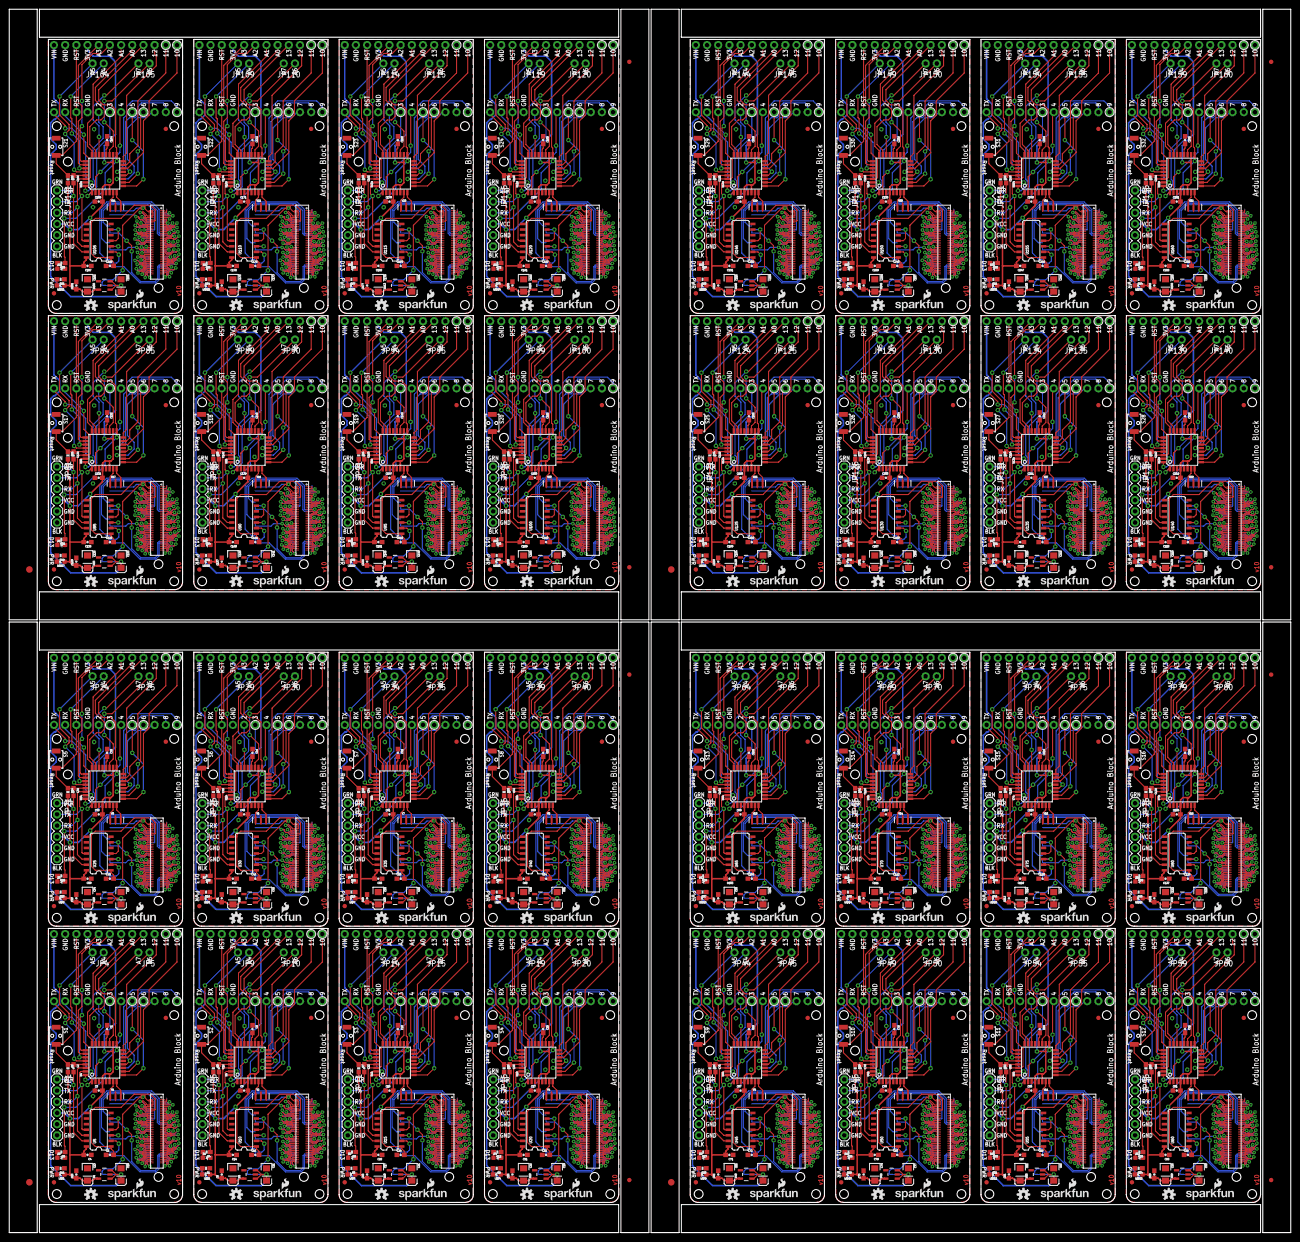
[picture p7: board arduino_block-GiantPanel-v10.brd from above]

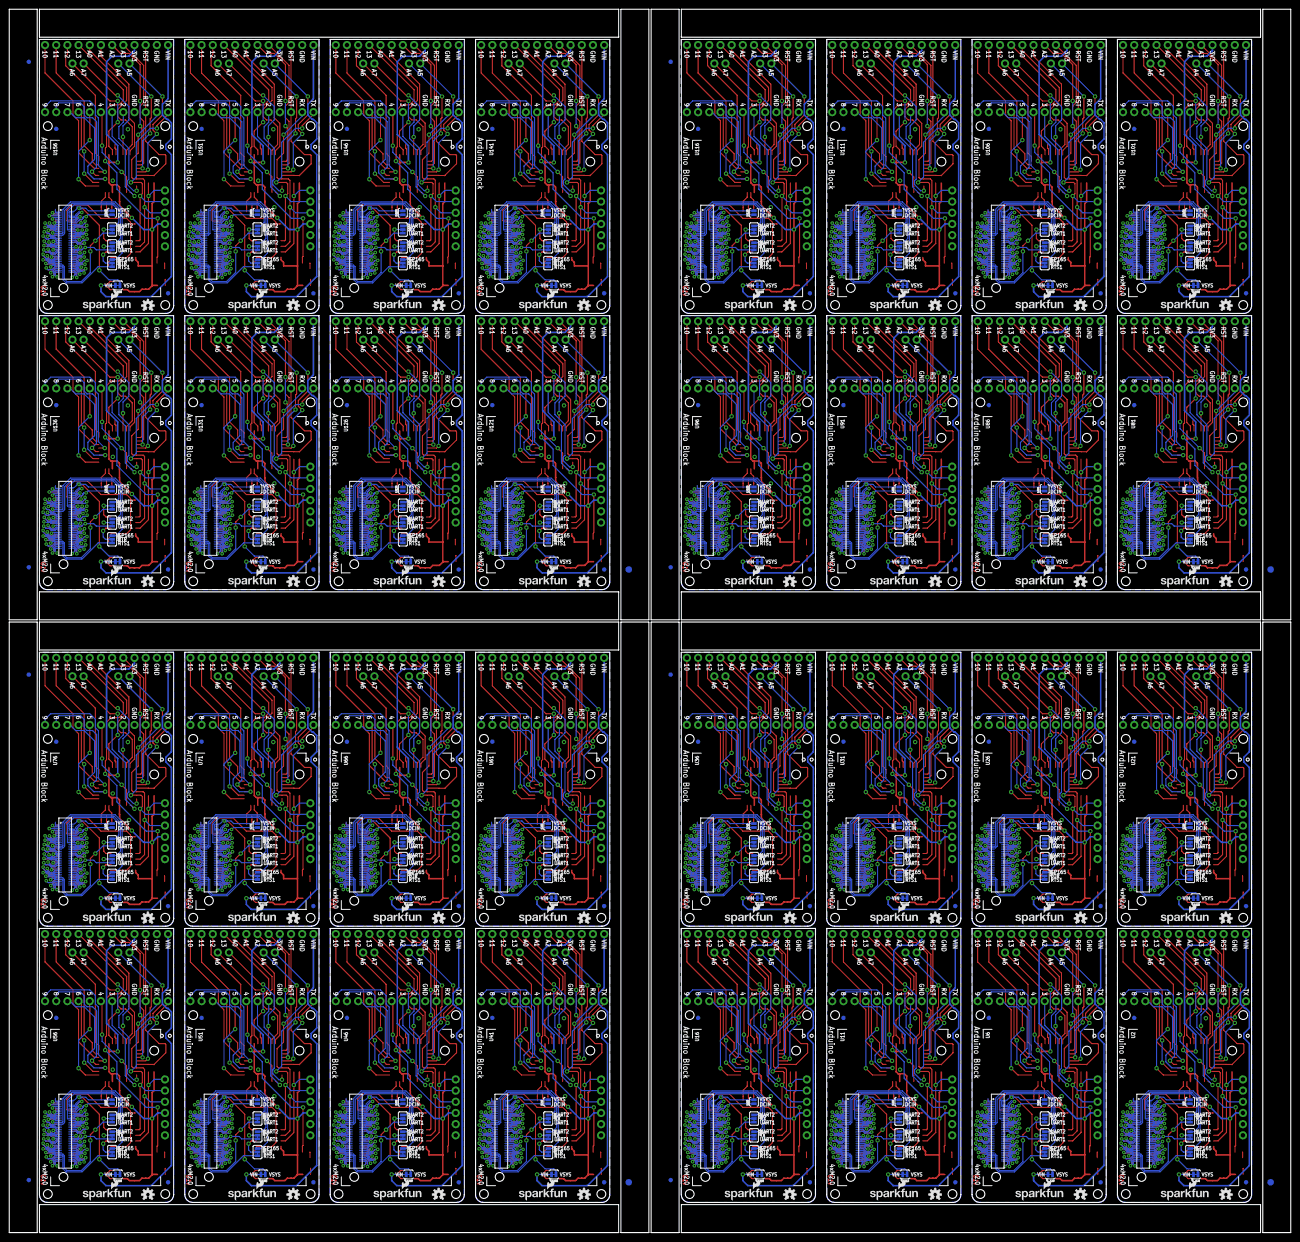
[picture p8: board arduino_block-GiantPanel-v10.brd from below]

Board: 2 copper layers, 291.1 x 277.9 mm, 1240 parts (364 on the bottom side), 2944 nets.

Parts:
C1, C2, C3, C4, C5, C6, C8, C9, C10, C12, C14, C15, C16, C18, C20, C22, C23, C24, C25, C27, C28, C30, C31, C32, C33, C35, C36, C38, C39, C40, C41, C43, C44, C46, C47, C48, C49, C51, C52, C54, C55, C56, C57, C59, C60, C62, C63, C64, C65, C67, C68, C70, C71, C72, C73, C75, C76, C78, C79, C80, C81, C83, C84, C86, C87, C88, C89, C91, C92, C94, C95, C96, C97, C99, C100, C102, C103, C104, C105, C107, C108, C110, C111, C112, C113, C115, C116, C118, C119, C120, C121, C123, C124, C126, C127, C128, C129, C131, C132, C134, C135, C136, C137, C139, C140, C142, C143, C144, C145, C147, C148, C150, C151, C152, C153, C155, C156, C158, C159, C160, C161, C163, C164, C166, C167, C168, C169, C171, C172, C174, C175, C176, C177, C179, C180, C182, C183, C184, C185, C187, C188, C190, C191, C192, C193, C195, C196, C198, C199, C200, C201, C203, C204, C206, C207, C208, C209, C211, C212, C214, C215, C216, C217, C219, C220, C222, C223, C224, C225, C227, C228, C230, C231, C232, C233, C235, C236, C238, C239, C240, C241, C243, C244, C246, C247, C248, C249, C251, C252, C254, C255, C256: 0.1uF; 0603-CAP
C7, C11, C13, C17, C19, C21, C26, C29, C34, C37, C42, C45, C50, C53, C58, C61, C66, C69, C74, C77, C82, C85, C90, C93, C98, C101, C106, C109, C114, C117, C122, C125, C130, C133, C138, C141, C146, C149, C154, C157, C162, C165, C170, C173, C178, C181, C186, C189, C194, C197, C202, C205, C210, C213, C218, C221, C226, C229, C234, C237, C242, C245, C250, C253: 10uF; EIA3216
D1, D2, D3, D4, D5, D6, D7, D8, D9, D10, D11, D12, D13, D14, D15, D16, D17, D18, D19, D20, D21, D22, D23, D24, D25, D26, D27, D28, D29, D30, D31, D32: Green; 0603-LED-ALT1
E$1, E$2, E$9, E$10, E$15, E$16, E$21, E$22: FIDUCIAL-1.5X3
E$3, E$4, E$5, E$6, E$7, E$8, E$11, E$12, E$13, E$14, E$17, E$18, E$19, E$20, E$23, E$24: FIDUCIAL-1X2
FID1, FID2, FID3, FID4, FID5, FID6, FID7, FID8, FID9, FID10, FID11, FID12, FID13, FID14, FID15, FID16, FID17, FID18, FID19, FID20, FID21, FID22, FID23, FID24, FID25, FID26, FID27, FID28, FID29, FID30, FID31, FID32, FID33, FID34, FID35, FID36, FID37, FID38, FID39, FID40, FID41, FID42, FID43, FID44, FID45, FID46, FID47, FID48, FID49, FID50, FID51, FID52, FID53, FID54, FID55, FID56, FID57, FID58, FID59, FID60, FID61, FID62, FID63, FID64, FID65, FID66, FID67, FID68, FID69, FID70, FID71, FID72, FID73, FID74, FID75, FID76, FID77, FID78, FID79, FID80, FID81, FID82, FID83, FID84, FID85, FID86, FID87, FID88, FID89, FID90, FID91, FID92, FID93, FID94, FID95, FID96, FID97, FID98, FID99, FID100, FID101, FID102, FID103, FID104, FID105, FID106, FID107, FID108, FID109, FID110, FID111, FID112, FID113, FID114, FID115, FID116, FID117, FID118, FID119, FID120, FID121, FID122, FID123, FID124, FID125, FID126, FID127, FID128: FIDUCIAL1X2; FIDUCIAL-1X2
JP1, JP6, JP11, JP16, JP21, JP26, JP31, JP36, JP41, JP46, JP51, JP56, JP61, JP66, JP71, JP76, JP81, JP86, JP91, JP96, JP101, JP106, JP111, JP116, JP121, JP126, JP131, JP136, JP141, JP146, JP151, JP156: FTDI Basic; 1X06
JP2, JP3, JP7, JP8, JP12, JP13, JP17, JP18, JP22, JP23, JP27, JP28, JP32, JP33, JP37, JP38, JP42, JP43, JP47, JP48, JP52, JP53, JP57, JP58, JP62, JP63, JP67, JP68, JP72, JP73, JP77, JP78, JP82, JP83, JP87, JP88, JP92, JP93, JP97, JP98, JP102, JP103, JP107, JP108, JP112, JP113, JP117, JP118, JP122, JP123, JP127, JP128, JP132, JP133, JP137, JP138, JP142, JP143, JP147, JP148, JP152, JP153, JP157, JP158: M12NO_SILK; 1X12_NO_SILK
JP4, JP5, JP9, JP10, JP14, JP15, JP19, JP20, JP24, JP25, JP29, JP30, JP34, JP35, JP39, JP40, JP44, JP45, JP49, JP50, JP54, JP55, JP59, JP60, JP64, JP65, JP69, JP70, JP74, JP75, JP79, JP80, JP84, JP85, JP89, JP90, JP94, JP95, JP99, JP100, JP104, JP105, JP109, JP110, JP114, JP115, JP119, JP120, JP124, JP125, JP129, JP130, JP134, JP135, JP139, JP140, JP144, JP145, JP149, JP150, JP154, JP155, JP159, JP160: M021X02_NO_SILK; 1X02_NO_SILK
LED1, LED2, LED3, LED4, LED5, LED6, LED7, LED8, LED9, LED10, LED11, LED12, LED13, LED14, LED15, LED16, LED17, LED18, LED19, LED20, LED21, LED22, LED23, LED24, LED25, LED26, LED27, LED28, LED29, LED30, LED31, LED32: Red; 0603-LED-ALT1
LOGO1, LOGO2, LOGO5, LOGO7, LOGO9, LOGO11, LOGO13, LOGO15, LOGO17, LOGO19, LOGO21, LOGO23, LOGO25, LOGO27, LOGO29, LOGO31, LOGO33, LOGO35, LOGO37, LOGO39, LOGO41, LOGO43, LOGO45, LOGO47, LOGO49, LOGO51, LOGO53, LOGO55, LOGO57, LOGO59, LOGO61, LOGO63, LOGO65, LOGO67, LOGO69, LOGO71, LOGO73, LOGO75, LOGO77, LOGO79, LOGO81, LOGO83, LOGO85, LOGO87, LOGO89, LOGO91, LOGO93, LOGO95, LOGO97, LOGO99, LOGO101, LOGO103, LOGO105, LOGO107, LOGO109, LOGO111, LOGO113, LOGO115, LOGO117, LOGO119, LOGO121, LOGO123, LOGO125, LOGO127: OSHW-LOGOS; OSHW-LOGO-S
LOGO3, LOGO4, LOGO6, LOGO8, LOGO10, LOGO12, LOGO14, LOGO16, LOGO18, LOGO20, LOGO22, LOGO24, LOGO26, LOGO28, LOGO30, LOGO32, LOGO34, LOGO36, LOGO38, LOGO40, LOGO42, LOGO44, LOGO46, LOGO48, LOGO50, LOGO52, LOGO54, LOGO56, LOGO58, LOGO60, LOGO62, LOGO64, LOGO66, LOGO68, LOGO70, LOGO72, LOGO74, LOGO76, LOGO78, LOGO80, LOGO82, LOGO84, LOGO86, LOGO88, LOGO90, LOGO92, LOGO94, LOGO96, LOGO98, LOGO100, LOGO102, LOGO104, LOGO106, LOGO108, LOGO110, LOGO112, LOGO114, LOGO116, LOGO118, LOGO120, LOGO122, LOGO124, LOGO126, LOGO128: SFE_LOGO_NAME_FLAME.1_INCH; SFE_LOGO_NAME_FLAME_.1
R1, R2, R3, R5, R7, R9, R10, R11, R13, R14, R16, R17, R19, R20, R22, R23, R25, R26, R28, R29, R31, R32, R34, R35, R37, R38, R40, R41, R43, R44, R46, R47, R49, R50, R52, R53, R55, R56, R58, R59, R61, R62, R64, R65, R67, R68, R70, R71, R73, R74, R76, R77, R79, R80, R82, R83, R85, R86, R88, R89, R91, R92, R94, R95: 10K; 0603-RES
R4, R6, R8, R12, R15, R18, R21, R24, R27, R30, R33, R36, R39, R42, R45, R48, R51, R54, R57, R60, R63, R66, R69, R72, R75, R78, R81, R84, R87, R90, R93, R96: 330; 0603-RES
S1, S2, S3, S4, S5, S6, S7, S8, S9, S10, S11, S12, S13, S14, S15, S16, S17, S18, S19, S20, S21, S22, S23, S24, S25, S26, S27, S28, S29, S30, S31, S32: RESET; TACTILE_SWITCH-SMD-RIGHT-ANGLE
SJ1, SJ3, SJ6, SJ9, SJ11, SJ14, SJ16, SJ19, SJ21, SJ24, SJ26, SJ29, SJ31, SJ34, SJ36, SJ39, SJ41, SJ44, SJ46, SJ49, SJ51, SJ54, SJ56, SJ59, SJ61, SJ64, SJ66, SJ69, SJ71, SJ74, SJ76, SJ79, SJ81, SJ84, SJ86, SJ89, SJ91, SJ94, SJ96, SJ99, SJ101, SJ104, SJ106, SJ109, SJ111, SJ114, SJ116, SJ119, SJ121, SJ124, SJ126, SJ129, SJ131, SJ134, SJ136, SJ139, SJ141, SJ144, SJ146, SJ149, SJ151, SJ154, SJ156, SJ159: TX; PAD-JUMPER-3-2OF3_NC_BY_TRACE_YES_SILK_FULL_BOX
SJ2, SJ7, SJ12, SJ17, SJ22, SJ27, SJ32, SJ37, SJ42, SJ47, SJ52, SJ57, SJ62, SJ67, SJ72, SJ77, SJ82, SJ87, SJ92, SJ97, SJ102, SJ107, SJ112, SJ117, SJ122, SJ127, SJ132, SJ137, SJ142, SJ147, SJ152, SJ157: RX; PAD-JUMPER-3-2OF3_NC_BY_TRACE_YES_SILK_FULL_BOX
SJ4, SJ8, SJ13, SJ18, SJ23, SJ28, SJ33, SJ38, SJ43, SJ48, SJ53, SJ58, SJ63, SJ68, SJ73, SJ78, SJ83, SJ88, SJ93, SJ98, SJ103, SJ108, SJ113, SJ118, SJ123, SJ128, SJ133, SJ138, SJ143, SJ148, SJ153, SJ158: VIN; PAD-JUMPER-2-NC_BY_TRACE_YES_SILK
SJ5, SJ10, SJ15, SJ20, SJ25, SJ30, SJ35, SJ40, SJ45, SJ50, SJ55, SJ60, SJ65, SJ70, SJ75, SJ80, SJ85, SJ90, SJ95, SJ100, SJ105, SJ110, SJ115, SJ120, SJ125, SJ130, SJ135, SJ140, SJ145, SJ150, SJ155, SJ160: DCIN; PAD-JUMPER-2-NO_YES_SILK
U1, U8, U13, U18, U23, U28, U33, U38, U43, U48, U53, U58, U63, U68, U73, U78, U83, U88, U93, U98, U103, U108, U113, U118, U123, U128, U133, U138, U143, U148, U153, U158: MIC5205-3.3V (150mA); SOT23-5
U2, U6, U11, U16, U21, U26, U31, U36, U41, U46, U51, U56, U61, U66, U71, U76, U81, U86, U91, U96, U101, U106, U111, U116, U121, U126, U131, U136, U141, U146, U151, U156: EDISON_CONNECTOR_FULLMOUNTING_HOLES; EDISON_DAUGHTER
U3, U7, U12, U17, U22, U27, U32, U37, U42, U47, U52, U57, U62, U67, U72, U77, U82, U87, U92, U97, U102, U107, U112, U117, U122, U127, U132, U137, U142, U147, U152, U157: EDISON_CONNECTOR_FULLHEADER; DF40C-70DP-0.4(51)
U4, U9, U14, U19, U24, U29, U34, U39, U44, U49, U54, U59, U64, U69, U74, U79, U84, U89, U94, U99, U104, U109, U114, U119, U124, U129, U134, U139, U144, U149, U154, U159: ATMEGA328; TQFP32-08
U5, U10, U15, U20, U25, U30, U35, U40, U45, U50, U55, U60, U65, U70, U75, U80, U85, U90, U95, U100, U105, U110, U115, U120, U125, U130, U135, U140, U145, U150, U155, U160: SO14
Y1, Y2, Y3, Y4, Y5, Y6, Y7, Y8, Y9, Y10, Y11, Y12, Y13, Y14, Y15, Y16, Y17, Y18, Y19, Y20, Y21, Y22, Y23, Y24, Y25, Y26, Y27, Y28, Y29, Y30, Y31, Y32: 8MHZ; RESONATOR-SMD

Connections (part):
1.8V: C5.2, U2.12, U3.12, U5.1, U5.8
1.8V1: C15.2, U6.12, U7.12, U10.1, U10.8
1.8V2: C24.2, U11.12, U12.12, U15.1, U15.8
1.8V3: C32.2, U16.12, U17.12, U20.1, U20.8
1.8V4: C40.2, U21.12, U22.12, U25.1, U25.8
1.8V5: C48.2, U26.12, U27.12, U30.1, U30.8
1.8V6: C56.2, U31.12, U32.12, U35.1, U35.8
1.8V7: C64.2, U36.12, U37.12, U40.1, U40.8
1.8V8: C72.2, U41.12, U42.12, U45.1, U45.8
1.8V9: C80.2, U46.12, U47.12, U50.1, U50.8
1.8V10: C88.2, U51.12, U52.12, U55.1, U55.8
1.8V11: C96.2, U56.12, U57.12, U60.1, U60.8
1.8V12: C104.2, U61.12, U62.12, U65.1, U65.8
1.8V13: C112.2, U66.12, U67.12, U70.1, U70.8
1.8V14: C120.2, U71.12, U72.12, U75.1, U75.8
1.8V15: C128.2, U76.12, U77.12, U80.1, U80.8
1.8V16: C136.2, U81.12, U82.12, U85.1, U85.8
1.8V17: C144.2, U86.12, U87.12, U90.1, U90.8
1.8V18: C152.2, U91.12, U92.12, U95.1, U95.8
1.8V19: C160.2, U96.12, U97.12, U100.1, U100.8
1.8V20: C168.2, U101.12, U102.12, U105.1, U105.8
1.8V21: C176.2, U106.12, U107.12, U110.1, U110.8
1.8V22: C184.2, U111.12, U112.12, U115.1, U115.8
1.8V23: C192.2, U116.12, U117.12, U120.1, U120.8
1.8V24: C200.2, U121.12, U122.12, U125.1, U125.8
1.8V25: C208.2, U126.12, U127.12, U130.1, U130.8
1.8V26: C216.2, U131.12, U132.12, U135.1, U135.8
1.8V27: C224.2, U136.12, U137.12, U140.1, U140.8
1.8V28: C232.2, U141.12, U142.12, U145.1, U145.8
1.8V29: C240.2, U146.12, U147.12, U150.1, U150.8
1.8V30: C248.2, U151.12, U152.12, U155.1, U155.8
1.8V31: C256.2, U156.12, U157.12, U160.1, U160.8
3.3V: U2.8, U2.10, U3.8, U3.10
3.3V1: U6.8, U6.10, U7.8, U7.10
3.3V2: U11.8, U11.10, U12.8, U12.10
3.3V3: U16.8, U16.10, U17.8, U17.10
3.3V4: U21.8, U21.10, U22.8, U22.10
3.3V5: U26.8, U26.10, U27.8, U27.10
3.3V6: U31.8, U31.10, U32.8, U32.10
3.3V7: U36.8, U36.10, U37.8, U37.10
3.3V8: U41.8, U41.10, U42.8, U42.10
3.3V9: U46.8, U46.10, U47.8, U47.10
3.3V10: U51.8, U51.10, U52.8, U52.10
3.3V11: U56.8, U56.10, U57.8, U57.10
3.3V12: U61.8, U61.10, U62.8, U62.10
3.3V13: U66.8, U66.10, U67.8, U67.10
3.3V14: U71.8, U71.10, U72.8, U72.10
3.3V15: U76.8, U76.10, U77.8, U77.10
3.3V16: U81.8, U81.10, U82.8, U82.10
3.3V17: U86.8, U86.10, U87.8, U87.10
3.3V18: U91.8, U91.10, U92.8, U92.10
3.3V19: U96.8, U96.10, U97.8, U97.10
3.3V20: U101.8, U101.10, U102.8, U102.10
3.3V21: U106.8, U106.10, U107.8, U107.10
3.3V22: U111.8, U111.10, U112.8, U112.10
3.3V23: U116.8, U116.10, U117.8, U117.10
3.3V24: U121.8, U121.10, U122.8, U122.10
3.3V25: U126.8, U126.10, U127.8, U127.10
3.3V26: U131.8, U131.10, U132.8, U132.10
3.3V27: U136.8, U136.10, U137.8, U137.10
3.3V28: U141.8, U141.10, U142.8, U142.10
3.3V29: U146.8, U146.10, U147.8, U147.10
3.3V30: U151.8, U151.10, U152.8, U152.10
3.3V31: U156.8, U156.10, U157.8, U157.10
A0: JP2.8, U4.23
A1: JP2.7, U4.24
A2: JP2.6, U4.25
A3: JP2.5, U4.26
A4: JP4.1, U4.27
A5: JP4.2, U4.28
A6: JP5.1, U4.19
A7: JP5.2, U4.22
A8: JP9.2, U9.28
A9: JP9.1, U9.27
A10: JP7.5, U9.26
A11: JP7.6, U9.25
A12: JP7.7, U9.24
A13: JP7.8, U9.23
A14: JP10.1, U9.19
A15: JP10.2, U9.22
A16: JP14.2, U14.28
A17: JP14.1, U14.27
A18: JP12.5, U14.26
A19: JP12.6, U14.25
A20: JP12.7, U14.24
A21: JP12.8, U14.23
A22: JP15.1, U14.19
A23: JP15.2, U14.22
A24: JP19.2, U19.28
A25: JP19.1, U19.27
A26: JP17.5, U19.26
A27: JP17.6, U19.25
A28: JP17.7, U19.24
A29: JP17.8, U19.23
A30: JP20.1, U19.19
A31: JP20.2, U19.22
A32: JP24.2, U24.28
A33: JP24.1, U24.27
A34: JP22.5, U24.26
A35: JP22.6, U24.25
A36: JP22.7, U24.24
A37: JP22.8, U24.23
A38: JP25.1, U24.19
A39: JP25.2, U24.22
A40: JP29.2, U29.28
A41: JP29.1, U29.27
A42: JP27.5, U29.26
A43: JP27.6, U29.25
A44: JP27.7, U29.24
A45: JP27.8, U29.23
A46: JP30.1, U29.19
A47: JP30.2, U29.22
A48: JP34.2, U34.28
A49: JP34.1, U34.27
A50: JP32.5, U34.26
A51: JP32.6, U34.25
A52: JP32.7, U34.24
A53: JP32.8, U34.23
A54: JP35.1, U34.19
A55: JP35.2, U34.22
A56: JP39.2, U39.28
A57: JP39.1, U39.27
A58: JP37.5, U39.26
A59: JP37.6, U39.25
A60: JP37.7, U39.24
A61: JP37.8, U39.23
A62: JP40.1, U39.19
A63: JP40.2, U39.22
A64: JP44.2, U44.28
A65: JP44.1, U44.27
A66: JP42.5, U44.26
A67: JP42.6, U44.25
A68: JP42.7, U44.24
A69: JP42.8, U44.23
A70: JP45.1, U44.19
A71: JP45.2, U44.22
A72: JP49.2, U49.28
A73: JP49.1, U49.27
A74: JP47.5, U49.26
A75: JP47.6, U49.25
A76: JP47.7, U49.24
A77: JP47.8, U49.23
A78: JP50.1, U49.19
A79: JP50.2, U49.22
A80: JP54.2, U54.28
A81: JP54.1, U54.27
A82: JP52.5, U54.26
A83: JP52.6, U54.25
A84: JP52.7, U54.24
A85: JP52.8, U54.23
A86: JP55.1, U54.19
A87: JP55.2, U54.22
A88: JP59.2, U59.28
A89: JP59.1, U59.27
A90: JP57.5, U59.26
A91: JP57.6, U59.25
A92: JP57.7, U59.24
A93: JP57.8, U59.23
A94: JP60.1, U59.19
A95: JP60.2, U59.22
A96: JP64.2, U64.28
A97: JP64.1, U64.27
A98: JP62.5, U64.26
A99: JP62.6, U64.25
A100: JP62.7, U64.24
A101: JP62.8, U64.23
A102: JP65.1, U64.19
A103: JP65.2, U64.22
A104: JP69.2, U69.28
A105: JP69.1, U69.27
A106: JP67.5, U69.26
A107: JP67.6, U69.25
A108: JP67.7, U69.24
A109: JP67.8, U69.23
A110: JP70.1, U69.19
A111: JP70.2, U69.22
A112: JP74.2, U74.28
A113: JP74.1, U74.27
A114: JP72.5, U74.26
A115: JP72.6, U74.25
A116: JP72.7, U74.24
A117: JP72.8, U74.23
A118: JP75.1, U74.19
A119: JP75.2, U74.22
A120: JP79.2, U79.28
A121: JP79.1, U79.27
A122: JP77.5, U79.26
A123: JP77.6, U79.25
A124: JP77.7, U79.24
A125: JP77.8, U79.23
A126: JP80.1, U79.19
A127: JP80.2, U79.22
A128: JP84.2, U84.28
A129: JP84.1, U84.27
A130: JP82.5, U84.26
A131: JP82.6, U84.25
A132: JP82.7, U84.24
A133: JP82.8, U84.23
A134: JP85.1, U84.19
A135: JP85.2, U84.22
A136: JP89.2, U89.28
A137: JP89.1, U89.27
A138: JP87.5, U89.26
A139: JP87.6, U89.25
A140: JP87.7, U89.24
A141: JP87.8, U89.23
A142: JP90.1, U89.19
A143: JP90.2, U89.22
A144: JP94.2, U94.28
A145: JP94.1, U94.27
A146: JP92.5, U94.26
A147: JP92.6, U94.25
A148: JP92.7, U94.24
A149: JP92.8, U94.23
A150: JP95.1, U94.19
A151: JP95.2, U94.22
A152: JP99.2, U99.28
A153: JP99.1, U99.27
A154: JP97.5, U99.26
A155: JP97.6, U99.25
A156: JP97.7, U99.24
A157: JP97.8, U99.23
A158: JP100.1, U99.19
A159: JP100.2, U99.22
A160: JP104.2, U104.28
A161: JP104.1, U104.27
A162: JP102.5, U104.26
A163: JP102.6, U104.25
A164: JP102.7, U104.24
A165: JP102.8, U104.23
A166: JP105.1, U104.19
A167: JP105.2, U104.22
A168: JP109.2, U109.28
A169: JP109.1, U109.27
A170: JP107.5, U109.26
A171: JP107.6, U109.25
A172: JP107.7, U109.24
A173: JP107.8, U109.23
A174: JP110.1, U109.19
A175: JP110.2, U109.22
A176: JP114.2, U114.28
A177: JP114.1, U114.27
A178: JP112.5, U114.26
A179: JP112.6, U114.25
A180: JP112.7, U114.24
A181: JP112.8, U114.23
A182: JP115.1, U114.19
A183: JP115.2, U114.22
A184: JP119.2, U119.28
A185: JP119.1, U119.27
A186: JP117.5, U119.26
A187: JP117.6, U119.25
A188: JP117.7, U119.24
A189: JP117.8, U119.23
A190: JP120.1, U119.19
A191: JP120.2, U119.22
A192: JP124.2, U124.28
A193: JP124.1, U124.27
A194: JP122.5, U124.26
A195: JP122.6, U124.25
A196: JP122.7, U124.24
A197: JP122.8, U124.23
A198: JP125.1, U124.19
A199: JP125.2, U124.22
A200: JP129.2, U129.28
A201: JP129.1, U129.27
A202: JP127.5, U129.26
A203: JP127.6, U129.25
A204: JP127.7, U129.24
A205: JP127.8, U129.23
A206: JP130.1, U129.19
A207: JP130.2, U129.22
A208: JP134.2, U134.28
A209: JP134.1, U134.27
A210: JP132.5, U134.26
A211: JP132.6, U134.25
A212: JP132.7, U134.24
A213: JP132.8, U134.23
A214: JP135.1, U134.19
A215: JP135.2, U134.22
A216: JP139.2, U139.28
A217: JP139.1, U139.27
A218: JP137.5, U139.26
A219: JP137.6, U139.25
A220: JP137.7, U139.24
A221: JP137.8, U139.23
A222: JP140.1, U139.19
A223: JP140.2, U139.22
A224: JP144.2, U144.28
A225: JP144.1, U144.27
A226: JP142.5, U144.26
A227: JP142.6, U144.25
A228: JP142.7, U144.24
A229: JP142.8, U144.23
A230: JP145.1, U144.19
A231: JP145.2, U144.22
A232: JP149.2, U149.28
A233: JP149.1, U149.27
A234: JP147.5, U149.26
A235: JP147.6, U149.25
A236: JP147.7, U149.24
A237: JP147.8, U149.23
A238: JP150.1, U149.19
A239: JP150.2, U149.22
A240: JP154.2, U154.28
A241: JP154.1, U154.27
A242: JP152.5, U154.26
A243: JP152.6, U154.25
A244: JP152.7, U154.24
A245: JP152.8, U154.23
A246: JP155.1, U154.19
A247: JP155.2, U154.22
A248: JP159.2, U159.28
A249: JP159.1, U159.27
A250: JP157.5, U159.26
A251: JP157.6, U159.25
A252: JP157.7, U159.24
A253: JP157.8, U159.23
A254: JP160.1, U159.19
A255: JP160.2, U159.22
ARD_DTR: C2.2, JP1.1, U5.13
ARD_DTR1: C12.2, JP6.1, U10.13
ARD_DTR2: C22.2, JP11.1, U15.13
ARD_DTR3: C30.2, JP16.1, U20.13
ARD_DTR4: C38.2, JP21.1, U25.13
ARD_DTR5: C46.2, JP26.1, U30.13
ARD_DTR6: C54.2, JP31.1, U35.13
ARD_DTR7: C62.2, JP36.1, U40.13
ARD_DTR8: C70.2, JP41.1, U45.13
ARD_DTR9: C78.2, JP46.1, U50.13
ARD_DTR10: C86.2, JP51.1, U55.13
ARD_DTR11: C94.2, JP56.1, U60.13
ARD_DTR12: C102.2, JP61.1, U65.13
ARD_DTR13: C110.2, JP66.1, U70.13
ARD_DTR14: C118.2, JP71.1, U75.13
ARD_DTR15: C126.2, JP76.1, U80.13
ARD_DTR16: C134.2, JP81.1, U85.13
ARD_DTR17: C142.2, JP86.1, U90.13
ARD_DTR18: C150.2, JP91.1, U95.13
ARD_DTR19: C158.2, JP96.1, U100.13
ARD_DTR20: C166.2, JP101.1, U105.13
ARD_DTR21: C174.2, JP106.1, U110.13
ARD_DTR22: C182.2, JP111.1, U115.13
ARD_DTR23: C190.2, JP116.1, U120.13
ARD_DTR24: C198.2, JP121.1, U125.13
ARD_DTR25: C206.2, JP126.1, U130.13
ARD_DTR26: C214.2, JP131.1, U135.13
ARD_DTR27: C222.2, JP136.1, U140.13
ARD_DTR28: C230.2, JP141.1, U145.13
ARD_DTR29: C238.2, JP146.1, U150.13
ARD_DTR30: C246.2, JP151.1, U155.13
ARD_DTR31: C254.2, JP156.1, U160.13
ARD_RX: JP1.3, JP3.2, U4.30, U5.12
ARD_RX1: JP6.3, JP8.2, U9.30, U10.12
ARD_RX2: JP11.3, JP13.2, U14.30, U15.12
ARD_RX3: JP16.3, JP18.2, U19.30, U20.12
ARD_RX4: JP21.3, JP23.2, U24.30, U25.12
ARD_RX5: JP26.3, JP28.2, U29.30, U30.12
ARD_RX6: JP31.3, JP33.2, U34.30, U35.12
ARD_RX7: JP36.3, JP38.2, U39.30, U40.12
ARD_RX8: JP41.3, JP43.2, U44.30, U45.12
ARD_RX9: JP46.3, JP48.2, U49.30, U50.12
ARD_RX10: JP51.3, JP53.2, U54.30, U55.12
ARD_RX11: JP56.3, JP58.2, U59.30, U60.12
ARD_RX12: JP61.3, JP63.2, U64.30, U65.12
ARD_RX13: JP66.3, JP68.2, U69.30, U70.12
ARD_RX14: JP71.3, JP73.2, U74.30, U75.12
ARD_RX15: JP76.3, JP78.2, U79.30, U80.12
ARD_RX16: JP81.3, JP83.2, U84.30, U85.12
ARD_RX17: JP86.3, JP88.2, U89.30, U90.12
ARD_RX18: JP91.3, JP93.2, U94.30, U95.12
ARD_RX19: JP96.3, JP98.2, U99.30, U100.12
ARD_RX20: JP101.3, JP103.2, U104.30, U105.12
ARD_RX21: JP106.3, JP108.2, U109.30, U110.12
ARD_RX22: JP111.3, JP113.2, U114.30, U115.12
ARD_RX23: JP116.3, JP118.2, U119.30, U120.12
ARD_RX24: JP121.3, JP123.2, U124.30, U125.12
ARD_RX25: JP126.3, JP128.2, U129.30, U130.12
ARD_RX26: JP131.3, JP133.2, U134.30, U135.12
ARD_RX27: JP136.3, JP138.2, U139.30, U140.12
ARD_RX28: JP141.3, JP143.2, U144.30, U145.12
ARD_RX29: JP146.3, JP148.2, U149.30, U150.12
ARD_RX30: JP151.3, JP153.2, U154.30, U155.12
ARD_RX31: JP156.3, JP158.2, U159.30, U160.12
ARD_TX: JP1.2, JP3.1, U4.31, U5.11
ARD_TX1: JP6.2, JP8.1, U9.31, U10.11
ARD_TX2: JP11.2, JP13.1, U14.31, U15.11
ARD_TX3: JP16.2, JP18.1, U19.31, U20.11
ARD_TX4: JP21.2, JP23.1, U24.31, U25.11
ARD_TX5: JP26.2, JP28.1, U29.31, U30.11
ARD_TX6: JP31.2, JP33.1, U34.31, U35.11
ARD_TX7: JP36.2, JP38.1, U39.31, U40.11
ARD_TX8: JP41.2, JP43.1, U44.31, U45.11
ARD_TX9: JP46.2, JP48.1, U49.31, U50.11
ARD_TX10: JP51.2, JP53.1, U54.31, U55.11
ARD_TX11: JP56.2, JP58.1, U59.31, U60.11
ARD_TX12: JP61.2, JP63.1, U64.31, U65.11
ARD_TX13: JP66.2, JP68.1, U69.31, U70.11
ARD_TX14: JP71.2, JP73.1, U74.31, U75.11
ARD_TX15: JP76.2, JP78.1, U79.31, U80.11
ARD_TX16: JP81.2, JP83.1, U84.31, U85.11
ARD_TX17: JP86.2, JP88.1, U89.31, U90.11
ARD_TX18: JP91.2, JP93.1, U94.31, U95.11
ARD_TX19: JP96.2, JP98.1, U99.31, U100.11
ARD_TX20: JP101.2, JP103.1, U104.31, U105.11
ARD_TX21: JP106.2, JP108.1, U109.31, U110.11
ARD_TX22: JP111.2, JP113.1, U114.31, U115.11
ARD_TX23: JP116.2, JP118.1, U119.31, U120.11
ARD_TX24: JP121.2, JP123.1, U124.31, U125.11
ARD_TX25: JP126.2, JP128.1, U129.31, U130.11
ARD_TX26: JP131.2, JP133.1, U134.31, U135.11
ARD_TX27: JP136.2, JP138.1, U139.31, U140.11
ARD_TX28: JP141.2, JP143.1, U144.31, U145.11
ARD_TX29: JP146.2, JP148.1, U149.31, U150.11
ARD_TX30: JP151.2, JP153.1, U154.31, U155.11
ARD_TX31: JP156.2, JP158.1, U159.31, U160.11
AREF: C1.2, U4.20
AREF1: C9.2, U9.20
AREF2: C20.2, U14.20
AREF3: C28.2, U19.20
AREF4: C36.2, U24.20
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

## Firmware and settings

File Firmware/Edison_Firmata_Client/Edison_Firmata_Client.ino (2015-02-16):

/****************************************************************
   Edison Firmata Client
   by: Jim Lindblom @ SparkFun Electronics
   created on: Februrary 12, 2015
   github: https://github.com/sparkfun/Edison_Arduino_Block
   
   This is an Firmata client sketch for the Edison. It can
   communicate with an Arduino running Firmata over a Serial
   connection.
   
   Support for the following functions is written:
     firmata_init() -- set up firmata and pin reporting
     firmata_pinMode([pin], [0, 1, 2, 3, 4, 5, 6])
     firmata_digitalWrite([pin], [LOW/HIGH])
     firmata_analogWrite([pin], [0-255])
     firmata_analogRead([0-7])
     firmata_digitalRead([pin])
     firmata_servoWrite([pin], [value])
   
   Development Environment Specifics:
   Arduino 1.5.3 (for Edison)
   Intel Edison rev C
   Arduino Block for Edison
     Arduino should be running StandardFirmata
   
   This sketch is based on Firmata's processing client:
   https://github.com/firmata/processing
   As such, it is released under the same, free license. You can 
   redistribute it and/or modify it under the terms of the GNU 
   Lesser General Public License as published by the Free 
   Software Foundation; either version 2.1 of the License, or 
   (at your option) any later version.

   Distributed as-is; no warranty is given. 
****************************************************************/
// SerialEvent1 isn't defined in the Edison core (I think).
// To get some form of interrupt-driven Serial input, we'll read
// serial in on a timer.
#include <TimerOne.h>

#define MAX_DATA_BYTES 4096
#define MAX_PINS 128

// Pin Mode definitons:
// Use any of these six values to set a pin to INPUT, OUTPUT,
// ANALOG, PWM, SERVO, SHIFT, or I2C.
enum const_pin_mode {
  MODE_INPUT,  // 0
  MODE_OUTPUT, // 1
  MODE_ANALOG, // 2
  MODE_PWM,    // 3
  MODE_SERVO,  // 4
  MODE_SHIFT,  // 5
  MODE_I2C     // 6
};

// Message Types
// Used by the low-level Firmata functions to set up the 
// Firmata messages.
#define ANALOG_MESSAGE  0xE0
#define DIGITAL_MESSAGE 0x90
#define REPORT_ANALOG   0xC0
#define REPORT_DIGITAL  0xD0
#define START_SYSEX     0xF0
#define SET_PIN_MODE    0xF4
#define END_SYSEX       0xF7
#define REPORT_VERSION  0xF9
#define SYSTEM_RESET    0xFF

// Extended Commands:
// Used by the low-level Firmata functions to set up the 
// Firmata messages.
#define SERVO_CONFIG            0x70
#define STRING_DATA             0x71
#define SHIFT_DATA              0x75
#define I2C_REQUEST             0x76
#define I2C_REPLY               0x77
#define I2C_CONFIG              0x78
#define EXTENDED_ANALOG         0x6F
#define PIN_STATE_QUERY         0x6D
#define PIN_STATE_RESPONSE      0x6E
#define CAPABILITY_QUERY        0x6B
#define CAPABILITY_RESPONSE     0x6C
#define ANALOG_MAPPING_QUERY    0x69
#define ANALOG_MAPPING_RESPONSE 0x6A
#define REPORT_FIRMWARE         0x79
#define SAMPLING_INTERVAL       0x7A
#define SYSEX_NON_REALTIME      0x7E
#define SYSEX_REALTIME          0x7F

// Flags and variables to keep track of message reading status:
boolean parsingSysex = false;
int waitForData = 0;
int storedInputData[MAX_DATA_BYTES];
int sysexBytesRead = 0;
int executeMultiByteCommand = 0;
int multiByteChannel = 0;
// Variable arrays to keep track of pin values read in.
int digitalInputData[] = {0, 0, 0, 0, 0, 0, 0, 0, 
                          0, 0, 0, 0, 0, 0, 0, 0};
int analogInputData[] = {0, 0, 0, 0, 0, 0, 0, 0, 
                         0, 0, 0, 0, 0, 0, 0, 0};
int analogChannel[MAX_PINS];
boolean blinkFlag = false;

void setup()
{
  // Debug messages are sent out Serial. Use the Serial monitor
  // at 9600 bps to read pin values.
  Serial.begin(9600);
  
  // firmata_init sets up our firmata client. It tells the 
  // Firmata device to begin streaming analog values and any
  // digital pin value changes.
  firmata_init();
  
  // Use firmata_pinMode([pin], [value]) to set up pins on the
  // Firmata host:
  firmata_pinMode(13, MODE_OUTPUT); // LED tied to pin 13
  firmata_pinMode(4, MODE_INPUT);   // Digital input on pin 4
  firmata_pinMode(A0, MODE_ANALOG); // Analog input on pin 0
  firmata_pinMode(3, MODE_PWM);     // PWM LED on pin 3
}

void loop() 
{
  // Print the value of our Firmata Arduino's A0 pin:
  int a0Value = firmata_analogRead(0);
  Serial.print("A0: ");
  Serial.println(a0Value);
  
  
  // Print the value of our digital input on pin 4:
  int d4Value = firmata_digitalRead(4);
  Serial.print("Pin 4: ");
  Serial.println(d4Value);
  
  if (d4Value == LOW)
  {
    // Scale the value of A0 to write a PWM output on pin 3:
    firmata_analogWrite(3, firmata_analogRead(0) / 4);
  }
  else
  {
    // Scale the value of A0 to write a PWM output on pin 3:
    firmata_analogWrite(3, 0);
  }
  
}

///////////////////////////////////
// Upper Level Firmata Functions //
///////////////////////////////////
// Firmata functions that you should use in your sketch above.
// If this was a class, these'd be public functions.

// firmata_init() -- 
// - Initialize our Firmata Serial port. 
// - Set up a timer to read in Serial messages outside of loop().
// - Configure our Firmata Arduino to report all digital outputs
// - Configure our Firmata Arduino to report all analog outputs
void firmata_init()
{
  Serial1.begin(57600);
  // set a timer of length 100,000 microseconds ( 0.1 sec - or 10Hz)
  Timer1.initialize(1000); 
  Timer1.attachInterrupt( checkSerial ); // attach the service routine here
  
  // Turn on reporting for all digital ports
  for (int i=0; i<16; i++)
  {
    Serial1.write(REPORT_DIGITAL | i);
    Serial1.write(1);
  }
  // This function will check for analog channels and set them
  // to REPORTING
  firmata_queryAnalogMapping();
}

// firmata_digitalRead([pin]) --
// - Returns the latest digital input value we've read on the
//   requested pin.
// - digitalInputData[] is updated in firmata_processInput()
//   as serial messages come in.
int firmata_digitalRead(int pin)
{
  return (digitalInputData[pin >> 3] >> (pin & 0x07)) & 0x01;
}

// firmata_analogRead([pin])
// - Returns the latest analog value we've read on the requested
//   pin.
// - analogInputData[] is updated in firmata_processInput()
//   as serial messages come in.
int firmata_analogRead(int pin)
{
  return analogInputData[pin];
}

// firmata_pinMode([pin], [mode])
// - Set an Arduino pin to input, output, analog in, PWM, servo,
//   shift register, or i2c.
// - [pin] - can be any Arduino pin 0-13, A0-A7
// - [mode] - should be one of these defined values:
//          - MODE_INPUT  - Digital input
//          - MODE_OUTPUT - Digital output
//          - MODE_ANALOG - Analog input
//          - MODE_PWM    - Analog output
//          - MODE_SERVO  - Servo output
//          - MODE_SHIFT  - Shift register output
void firmata_pinMode(int pin, int mode)
{
  Serial1.write(SET_PIN_MODE);
  Serial1.write(pin);
  Serial1.write(mode);
}

// firmata_digitalWrite([pin], [value])
// - Set an Arduino digital pin to HIGH or LOW
// - [pin] - Any digital pin 0-18
// - [value] - LOW or HIGH
void firmata_digitalWrite(int pin, int value)
{
  int port = (pin >> 3) & 0x0F;
  int data;
  
  if (value)
    data |= (1 << (pin & 0x07));
  else
    data &= ~(1 << (pin & 0x07));
    
  Serial1.write(DIGITAL_MESSAGE | port); // Digital data
  Serial1.write(data & 0x7F); // Digital pins 0-6 bitmask
  Serial1.write(data >> 7);   // Digital pin 7 bitmask
}

// firmata_analogWrite([pin], [value])
// - Set an Arduino pin - CONFIGURED AS PWM (!) - to an
//   analog output value.
// - [pin] - Any analog output capable pin (3, 5, 6, 9, 10, 11
// - [value] - 0-255
void firmata_analogWrite(int pin, int value)
{
    
  Serial1.write(ANALOG_MESSAGE | (pin& 0x0F)); // Analog pin
  Serial1.write(value & 0x7F); // Analog LS 7 bits
  Serial1.write(value >> 7);   // Analog MS 7 bits
}

// firmata_servoWrite([pin], [value])
// - Set an Arduino pin - CONFIGURED AS SERVO (!) - to output
//   a servo signal.
void firmata_servoWrite(int pin, int value)
{
  Serial1.write(ANALOG_MESSAGE | (pin & 0x0F));
  Serial1.write(value & 0x7F);
  Serial1.write(value >> 7);
}

/////////////////////////////////
// Low level Firmata functions //
/////////////////////////////////
// Firmata helper functions you probably won't need to call in
// your sketch. If this was a class, these'd be private functions.

// checkSerial()
// Interrupt-recurring function. Checks for available serial data
// and processes any serial messages that come in.
void checkSerial()
{
  while (Serial1.available())
  {
    //Serial.write(Serial1.read());
    firmata_processInput((unsigned char) Serial1.read());
  }
  if (blinkFlag)
  {
    firmata_digitalWrite(13, HIGH); // Tell Arduino to write 13 HIGH
    blinkFlag = false;
  }
  else
  {
    firmata_digitalWrite(13, LOW); // Tell Arduino to write 13 HIGH
    blinkFlag = true;
  }
}

// firmata_processInput([inputData])
// Handles all Firmata messages - everything from version checks
// to analog and digital readings.
void firmata_processInput(unsigned char inputData)
{
  int command;
  
  if (parsingSysex) // If we're parsing a system message
  {
    if (inputData == END_SYSEX)
    { // Received end of system message, process it
      parsingSysex = false;
      firmata_processSysexMessage();
    }
    else
    { // In the system message, add to it
      storedInputData[sysexBytesRead] = inputData;
      sysexBytesRead++;
    }
  }
  else if (waitForData > 0 && inputData < 128)
  { // Else waiting for data
    waitForData--; // Decrement wait for data
    storedInputData[waitForData] = inputData;
    
    if (executeMultiByteCommand != 0 && waitForData == 0)
    {
      switch(executeMultiByteCommand)
      {
      case DIGITAL_MESSAGE:
        firmata_setDigitalInputs(multiByteChannel, 
                 (storedInputData[0] << 7) + storedInputData[1]);
        break; 
      case ANALOG_MESSAGE:
        firmata_setAnalogInput(multiByteChannel, 
                 (storedInputData[0] << 7) + storedInputData[1]);
        break; 
      case REPORT_VERSION:
        firmata_setVersion(storedInputData[1], storedInputData[0]);
        break; 
      }
    }
  }
  else // Beginning of a message
  {
    if (inputData < 0xF0)
    {
      command = inputData & 0xF0;
      multiByteChannel = inputData & 0x0F;
    }
    else
    {
      command = inputData;
    }
    switch (command)
    {
    case DIGITAL_MESSAGE:
    case ANALOG_MESSAGE:
    case REPORT_VERSION:
      waitForData = 2;
      executeMultiByteCommand = command;
      break;
    case START_SYSEX:
      parsingSysex = true;
      sysexBytesRead = 0;
      break;
    }
  }
}

// firmata_processSysexMessage()
// - Process a system message.
// - Mostly just handles defining which pins are analog channels.
void firmata_processSysexMessage()
{
  switch (storedInputData[0])
  {
  case ANALOG_MAPPING_RESPONSE:
    // Begin by setting every channel to NOT analog (127)
    for (int pin = 0; pin < sizeof(analogChannel); pin++)
      analogChannel[pin] = 127;
    // Enumerate analog channels:
    for (int i = 1; i < sysexBytesRead; i++)
      analogChannel[i - 1] = storedInputData[i];
    // Set each analog output to reporting
    for (int pin = 0; pin < sizeof(analogChannel); pin++)
    {
      if (analogChannel[pin] != 127)
      {
        Serial1.write(REPORT_ANALOG | analogChannel[pin]);
        Serial1.write(1);
      }
    }
    break;
  }
}

// firmata_queryAnalogMapping()
// - Send the ANALOG_MAPPING_QUERY request message.
// - Called in init to keep track of which pins are analog ins
void firmata_queryAnalogMapping()
{
  Serial1.write(START_SYSEX);
  Serial1.write(ANALOG_MAPPING_QUERY);
  Serial1.write(END_SYSEX);
}

// firmata_setDigitalInputs()
// - Set a value in the digitalInputData array to portData
void firmata_setDigitalInputs(int portNumber, int portData)
{
  digitalInputData[portNumber] = portData;
}

// firmata_setAnalogInput
// - Set an analog pin value to [value].
void firmata_setAnalogInput(int pin, int value)
{
  analogInputData[pin] = value;
}

void firmata_setVersion(int majorVersion, int minorVersion)
{
  //! Todo
}

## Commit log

2014-08-12 initial hardware commit
    [Edison_Mezzanine_ArduinoPro.brd, Edison_Mezzanine_ArduinoPro.sch]
2014-08-12 expanding out connector, matching it to Arduino Pro
    [Edison_Mezzanine_ArduinoPro.brd, Edison_Mezzanine_ArduinoPro.sch]
2014-08-20 updating board description in README
2014-08-29 fixing 12-pin connectors - using NO_SILK part now
    [Edison_Mezzanine_ArduinoPro.brd, Edison_Mezzanine_ArduinoPro.sch]
2014-09-18 Swapping jumpers to default to UART 1. Updating silk. (v02)
    [arduino_block.brd, arduino_block.sch]
2014-09-18 Stacking DCIN through. Adding jumper to potentially connect it to VSYS
    [arduino_block.brd, arduino_block.sch]
2014-09-19 Replaced reset button with new RA SMD push button
    [arduino_block.brd, arduino_block.sch]
2014-09-19 moved board name to lower corner of keepout.
    [arduino_block.brd]
2014-09-23 cleaned up fills
    [arduino_block.brd]
2014-09-25 file cleanup
    [arduino_block.brd, arduino_block.sch]
2014-10-17 updating connector packages. Fixing silk.
    [arduino_block.brd, arduino_block.sch]
2014-10-17 fixing silk directions on bottom
    [arduino_block.brd]
2014-10-17 adjusting a few traces, relocating a jumper
    [arduino_block.brd]
2014-10-17 adding grn/blk labels to FTDI
    [arduino_block.brd]
2014-10-17 Tweak pwr and gnd traces on connectors. Reds.
    [arduino_block.brd, arduino_block.sch]
2014-10-17 Fixing a bit of silk placement
    [arduino_block.brd]
2014-10-17 Ready for reds. Moved some silk to be more readable along left edge of board. No known to-do items
    [arduino_block.brd]
2014-10-21 moved fid
    [arduino_block.brd]
2014-10-21 created panels
    [arduino_block-GiantPanel-v10.brd, arduino_block-Panel-v10.brd]
2015-04-01 Updating README and directory file names
    [arduino_block-GiantPanel-v10.brd, arduino_block-Panel-v10.brd]

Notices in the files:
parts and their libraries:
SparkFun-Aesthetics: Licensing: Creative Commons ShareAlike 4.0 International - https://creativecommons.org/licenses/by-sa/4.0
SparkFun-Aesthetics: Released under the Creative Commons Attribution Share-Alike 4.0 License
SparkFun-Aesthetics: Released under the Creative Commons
